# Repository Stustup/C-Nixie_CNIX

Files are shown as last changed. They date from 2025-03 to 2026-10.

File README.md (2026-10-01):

# CNIX - Nixie Tube Clock

CNIX is a nixie tube clock that can accept many diffrent nixie tubes with only slight modifications to the tube carrier board. 

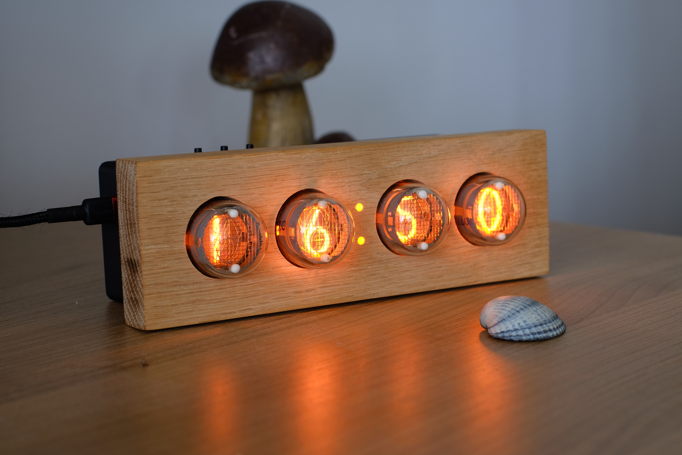
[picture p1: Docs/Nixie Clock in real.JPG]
Nixie Clock finished real picture


The motivation was that there are not many clocks out there that let you use almost any nixie tube you like. Most have fixed power supplies, 
underdesigned driver stages or inflexible microcontrollers. I hope to tackle these problems with an adjustable boost converter PSU, extremely 
flexible (and electrically protected) driver stages and an open source firmware written with free tools.

Nixie Clock PCB stackup

## **Schematic**

The control board consists of 3 parts:
- Power Supply
- Microcontroller
- I/O
- GPIO header

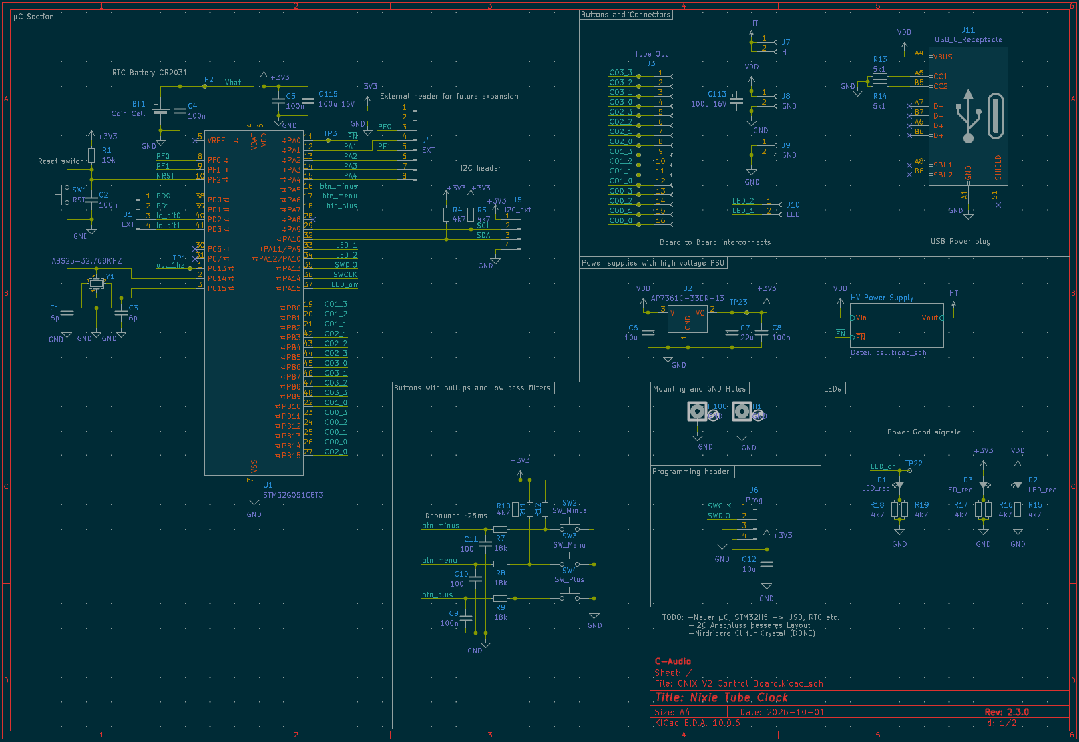
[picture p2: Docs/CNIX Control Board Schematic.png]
Control board schematic


Power comes from a simple USB-C plug configured for 5V 3A max with the 5k1 CC line resistors. I thought about adding a PD controller for higher input voltages, but this would just have added complexity and locked you into more expensive USB PD power supplies.

The µC is a STM32G051, because it has an included RTC *with* added Vbat pin for an external battery, so that the RTC remembers time even when powered off. 
The unused GPIOs are broken out to a connector, so that in the future one could add cool stuff like a radio time reciever, a display or wifi.
Time is set manually with the push buttons on top. 

The PSU is heavily inspired by [this site](https://surfncircuits.com/2018/02/03/optimizing-the-5v-to-170v-nixie-tube-power-supply-design-part-2/). I highly advise you giving it a read. The article goes in depth with boost converter design and its challanges.

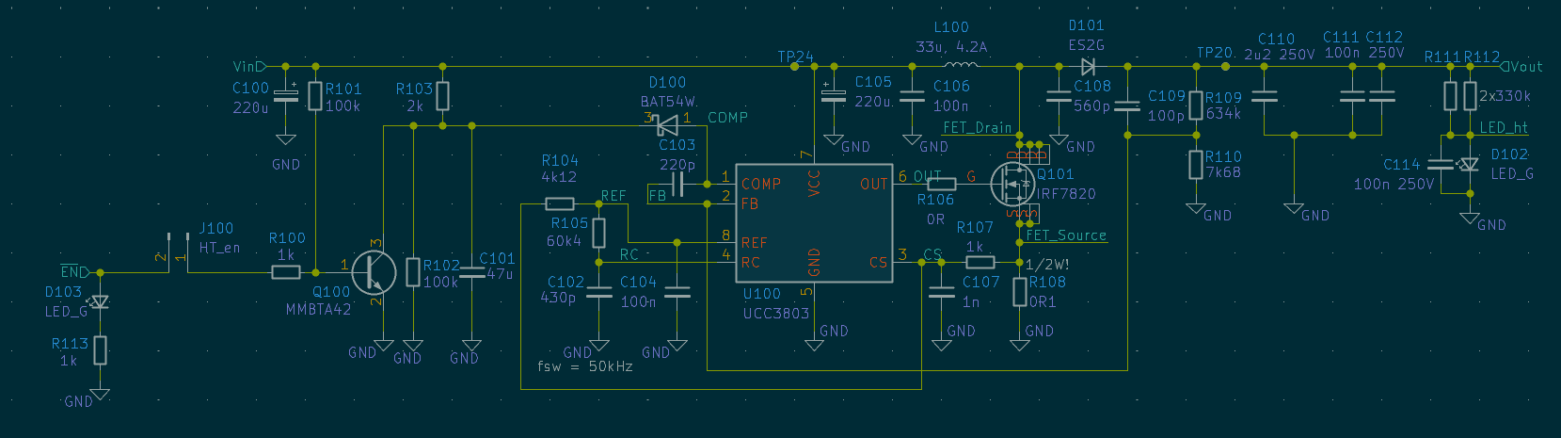
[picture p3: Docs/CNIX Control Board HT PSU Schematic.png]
HT Power supply

The ht power supply is a DCM boost converter powered by the UCC3803. An active low enable pin is realized via pulling the frequency RC combination low. With normal usage temperature of around 50-60°C are reached by the output transistor and the controller, which is a safe area. The case is designed so that a convection current of air is directed over the power supply at all times. This vent should not be blocked.  

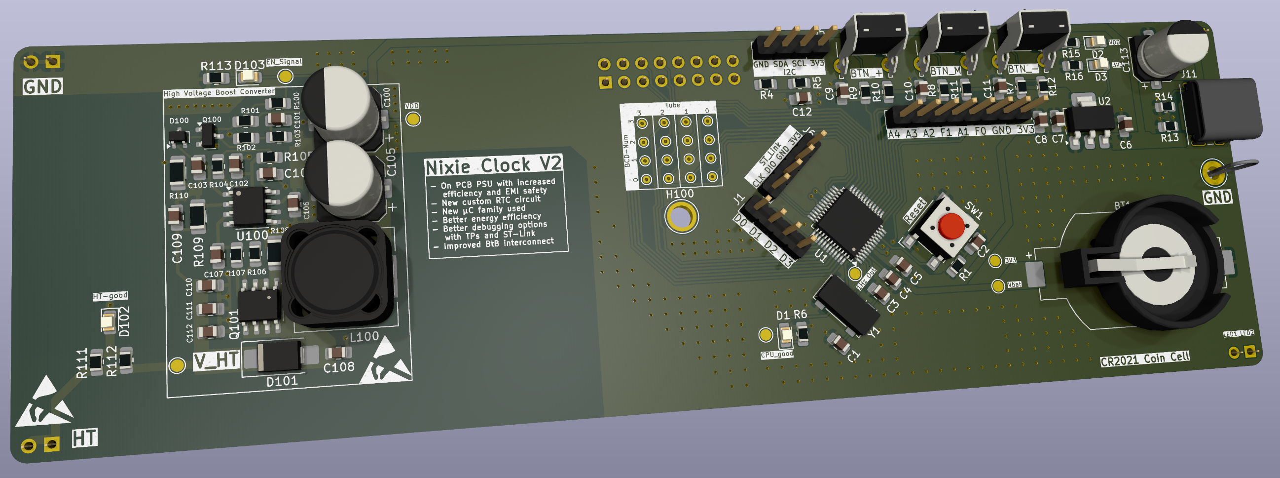
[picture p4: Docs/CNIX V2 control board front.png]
Control board 3d view


The driver consists of 4 CD4028 BCD to Decimal converters and 6 SN75468 high voltage drivers. The SN75468 only work up top 100V, but when using two 48V zener diodes as clamps, the voltage on the torned off digits never reach above 100V and above the startup voltage of the nixies. So win win.

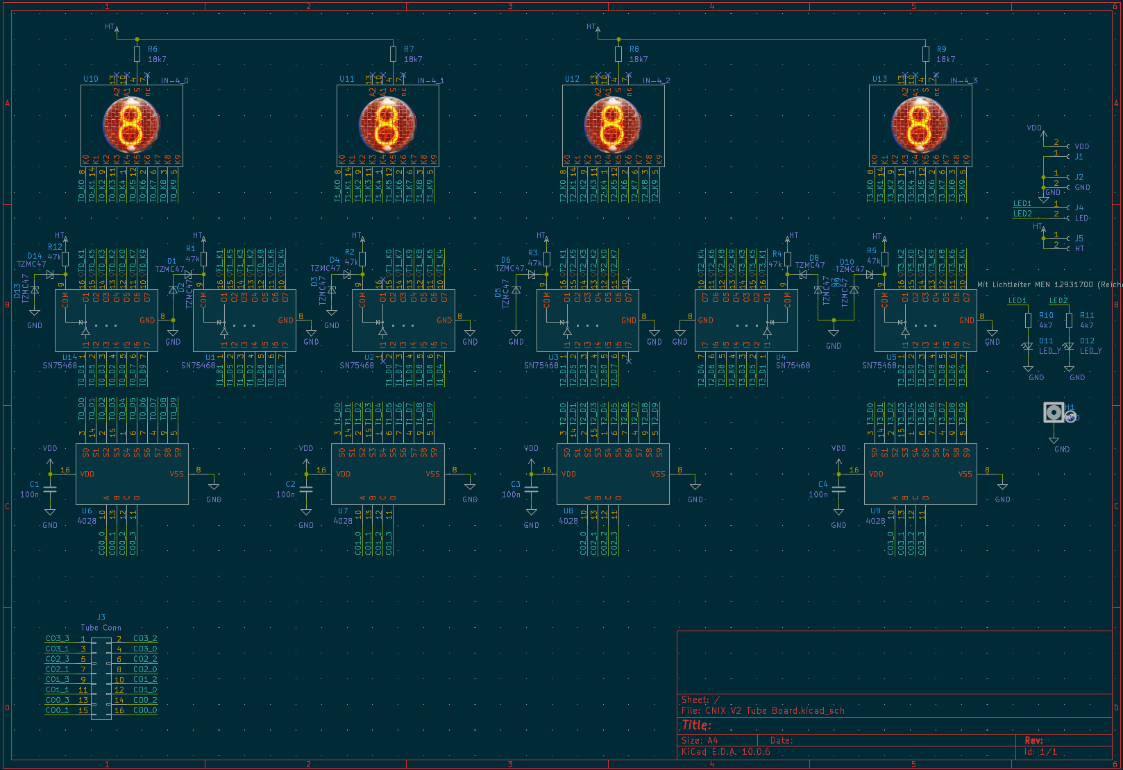
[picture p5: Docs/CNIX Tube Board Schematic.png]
Tube board schematic

I didn't use the old high voltage nixie driving shift registers as they are more and more hard to find for a reasonable price. Also i did not use shift registers at all, to simplify programming and wiring. Instead the whole Port B of the STM32 is used as a big 16 bit control register where the numbers are encoded in BCD. This ensures that there can not be 2 turned on digits at the same time in one tube to prevent bugs and damaging the beautiful nixies. 
Except the decoupling capacitors, diopdes and LEDS, everything is a simple to reflow solder IC, The tube pins have to be assembled manually (by putting them on a tube an inserting it into the holes before soldering it to ensure perfect alignment).  

The case is designed in FreeCAD and printed in PLA or PETG. Assembly is a bit of a hassle, but the fit is perfect. You can print a front plate, but i think the clock is vastly more beautiful when paired with a wooden front plate. Drill files for this are within the CAD folder. The holes for the LED front indicators can be filled with a 3mm lightpipe cut to length, to get a beautiful finish. 
Case, PCB and front plate are screwed together with 15mm M3 wood screws.

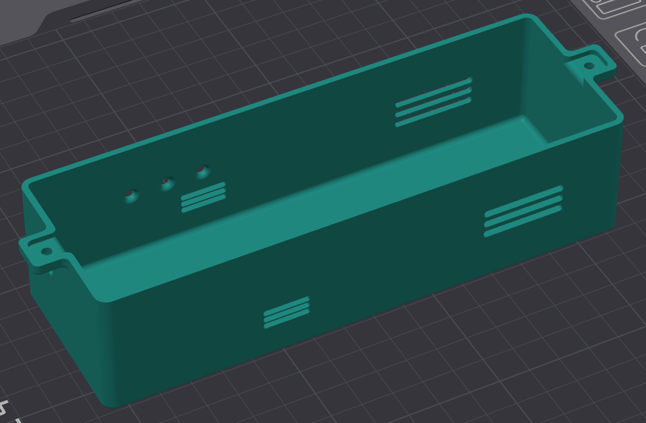
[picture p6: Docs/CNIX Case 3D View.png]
Case 3d view


## **Neat features**

### <u>Adaptability</u>
If you want to use any other nixie (up to around 5mA per tube of HT supply current) just modify the tube board PCB to fit your tubes. The driver, power supply and control logic should all be compatible with any other tube. Of course you have to modify the driving circuit when not using the simple common anode topology.

### <u>USB-C support</u>
Use any USB power supply with a minimum current of 1.7A (The startup of the boost converter needs a lot of current) Standard power consumption is around 2W (400mA at 5V) when the boost converter is powered on and around 0.2W (40mA at 5V) when the boost converter is powered down. 

### <u>Fallback structure</u>
If for some reason you change your mind while setting the start/stop times or the main time, just wait for around a minute. The menu will exit automatically, discard all changes and get back to the main time display.

### <u>Date and Sensor display</u>
Press the "plus" or "minus" buttons to cycle through submenus in this order: 
Main Time display -> Date display -> Sensor Display
These have a short timeout time to get back to the main Time menu. The sensor display gets disabled when there is no sensor addon board present.

### <u>Automatic daylight saving time (DST)</u>
The clock will calculate DST on its own and set the time correspondingly, even when the DCF77 module is not used.

### <u>Turn on/off timers</u>
You can set power on and off times in the clock natively, so that the nixies dont always glow. With this the HT-power supply also gets deactivated to save power and lifespan of the parts. 
There are two sets of start and stop times set by the buttons on the menu with the lower LED blinking.
The order is: Start1 -> Stop1 -> Start2 -> Stop2.
If all are set to 0, the start stop automatic gets disabled.
The start stop times are saved to a backup register of the µC, so the clock remembers them even when powered off as long as the RTC battery is present. 

#### Peek
When out of the "on" timeframes you can "peek" at the current time for 10s with a press of the menu-button. During these 10s you can jump to all the diffrent menus.

### <u>Addon Boards</u>
The breakout pins next to the µC can be used for addon boards. Pins D2 and D3 of the µC are used to detect those with an ID system. 
| ID | Board |
|---|---|
| 0b11  | No Addon board installed -> defualt |
| 0b00  | DCF77 Addon Board used |
| 0b01  | not yet used |
| 0b10  | not yet used |

Most of the hardware features of the STM32G051 should be mapped to the pins on the breakout. If not you're out of luck (it's open source, so just change it). Stuff like the ST-Link programming pins or I2C are broken out on extra headers to simplify future expansion.

#### DCF77 Addon Board
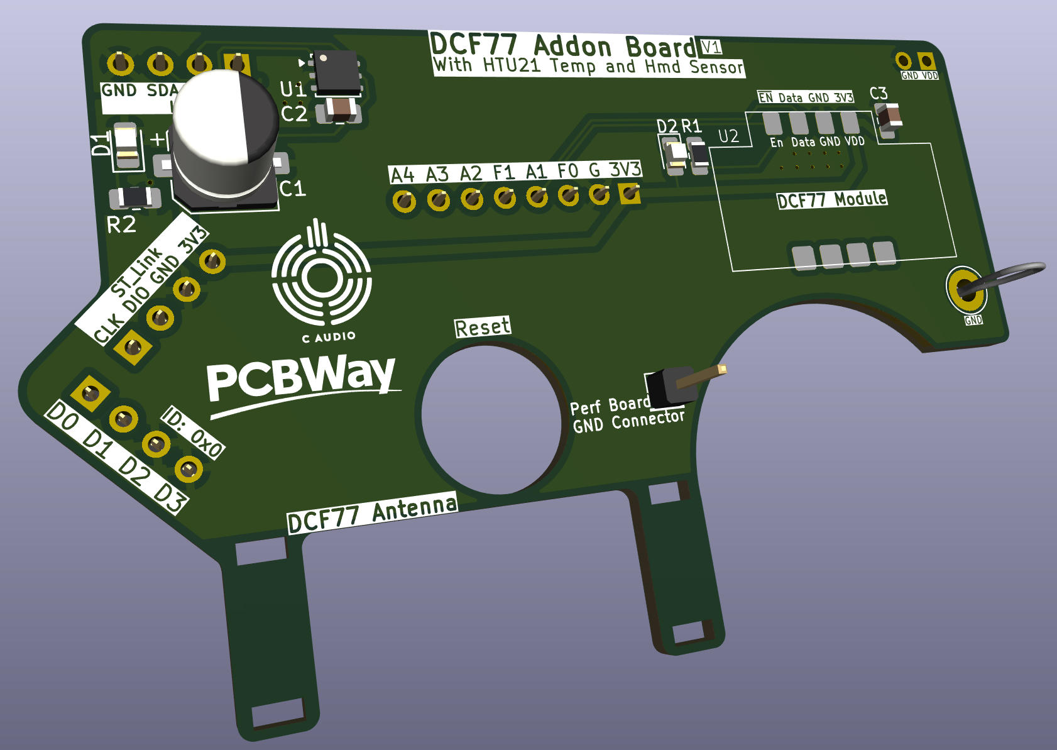
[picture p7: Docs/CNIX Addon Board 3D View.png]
DCF77 Addon Board

In germany (and most of europe) we have the DCF77 signal pushed out by the radio transmitter near Frankfurt. 
This board hosts a cheap module from ebay and a HTU21D temperature and humidity sensor. The driver is already programmed into the Control Board and gets enabled when this addon board is detected. 
When a valid time is recieved the manual timeSet menu gets disabled, to prevent fuckery.
It is setup, that every night at 2 an alarm gets triggered by the RTC to recalibrate time. If the  time-parity bit is not matched within a 20 minute timeout an attempt counter is incremented, which gets saved to a backup-register inside the RTC. As long as a RTC battery is powering the µC this register is kept even when the power is off. 
If the attempt counter reches 3 days without successful calibration against the radio time the manual timeSet menu gets enabled again.

On the DCF77 Addon board there is a single pin to give structural strength to a simple perfboard on the main breakout bus. One can use this in tandem with the A1, A2, A3, A4, F0 and F1 pins.

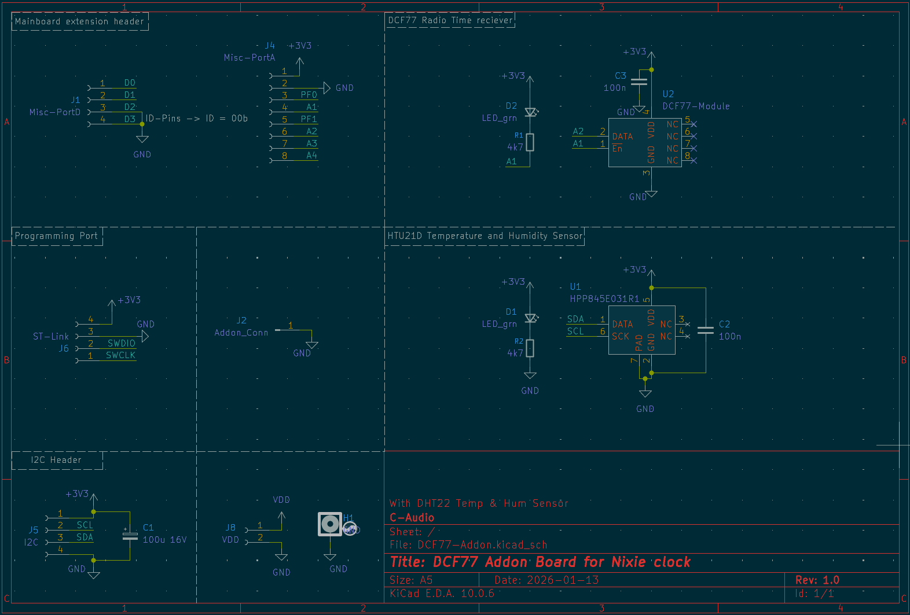
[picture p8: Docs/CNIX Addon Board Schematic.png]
DCF77 Addon Board


Ideas for future addon Boards: 
- ESP32 addon board to integrate WiFi time synchronisation or HomeAssistant integration
- Other sensors like air quality sensors
- maybe displays?

## TODO

- Change to new MCU. STM32H5 for USBC pd -> more efficient boost converter because higher input voltage
- Sleep modes during off times paired with wakeup alarms at start times -> reduce power consumption even more
- Improve the case to simplify assembly
- More tube boards to fit more types of nixies (IN-14 e.G.)
- BOM optimization to reduce number of unique parts
- galvanic isolation between high voltage areas and µC GPIOs

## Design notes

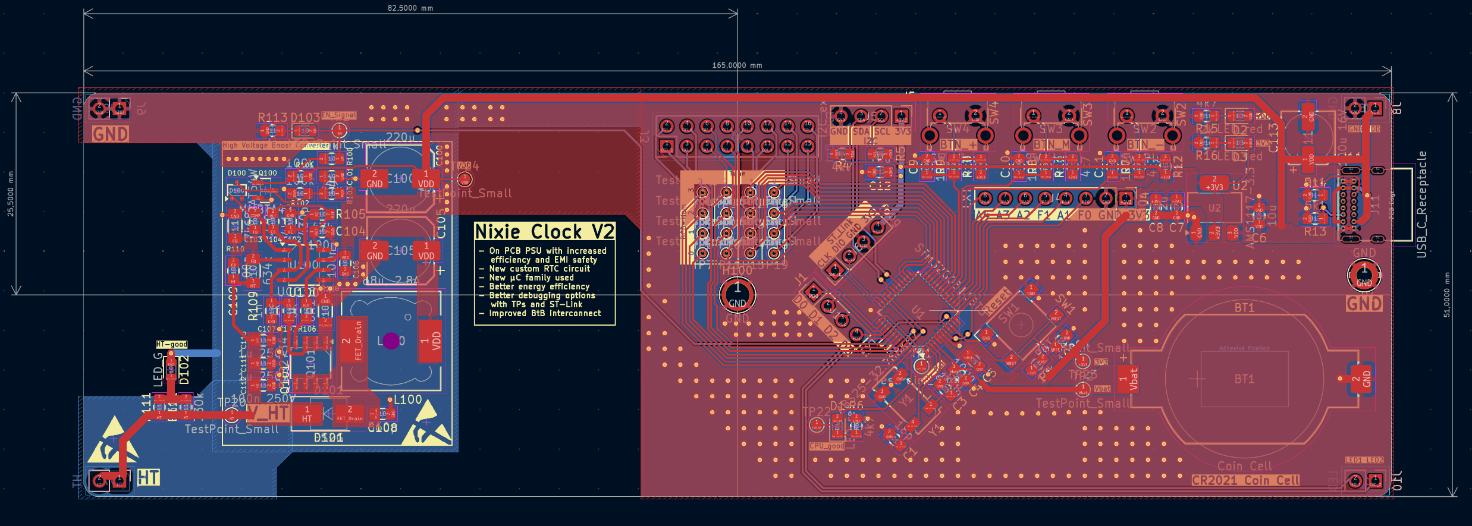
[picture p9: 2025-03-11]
Docs/CNIX V2 control board board.png

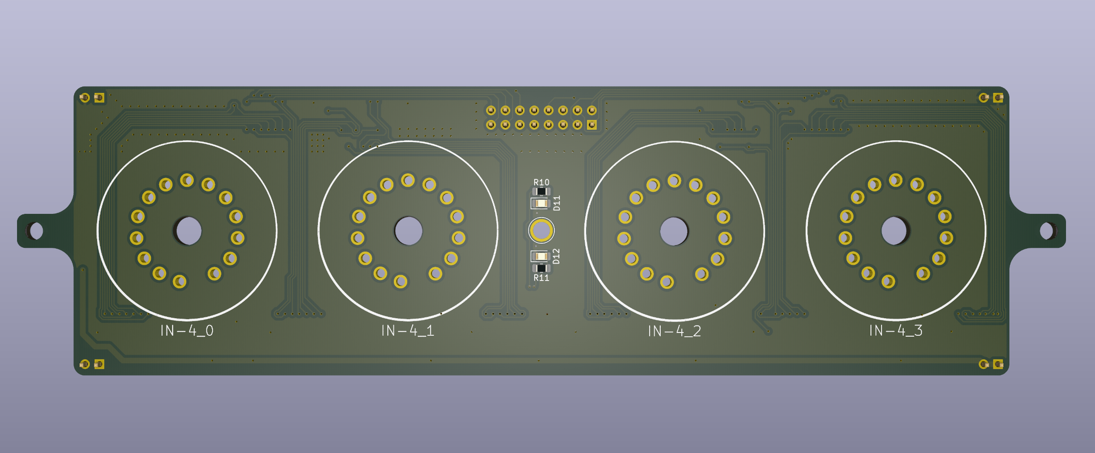
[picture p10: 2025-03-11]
Docs/CNIX V2 tube board front.png

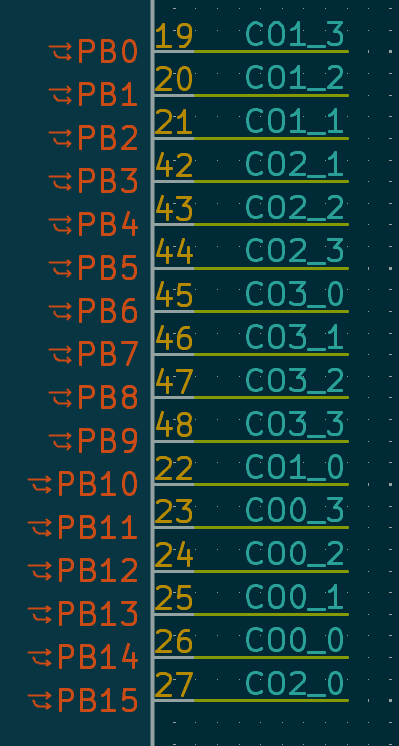
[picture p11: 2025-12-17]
Docs/Port mapping GPIOB.png

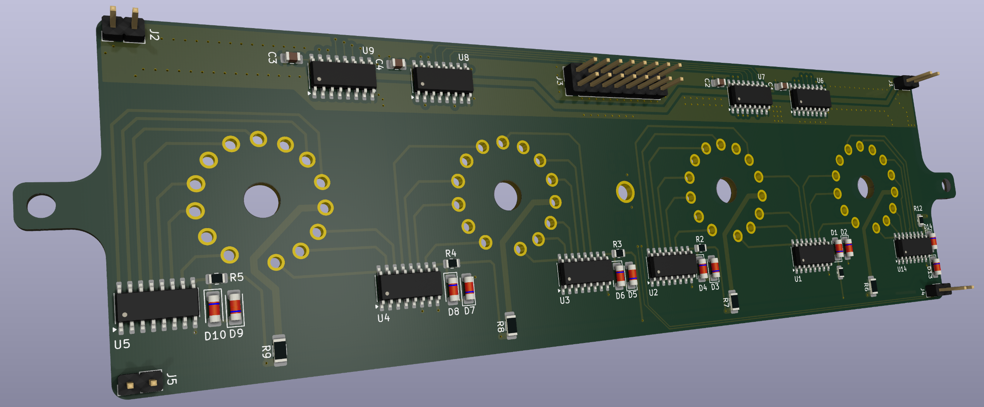
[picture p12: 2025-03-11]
Docs/CNIX V2 tube board side.png

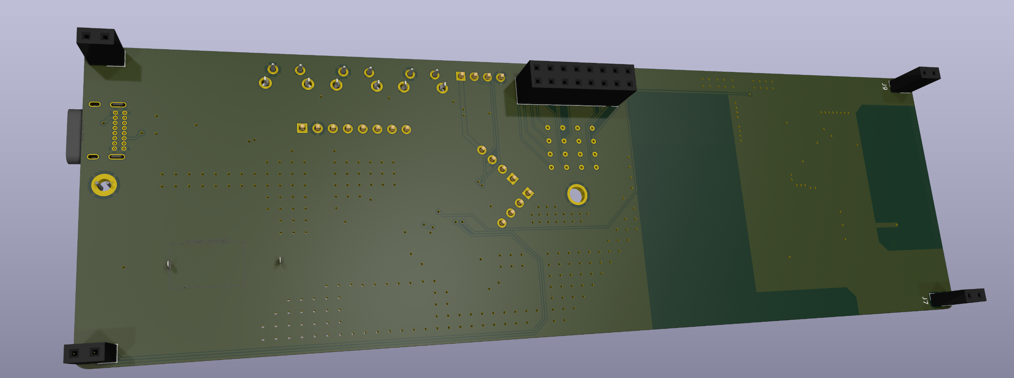
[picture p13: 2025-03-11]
Docs/CNIX V2 control board back.png

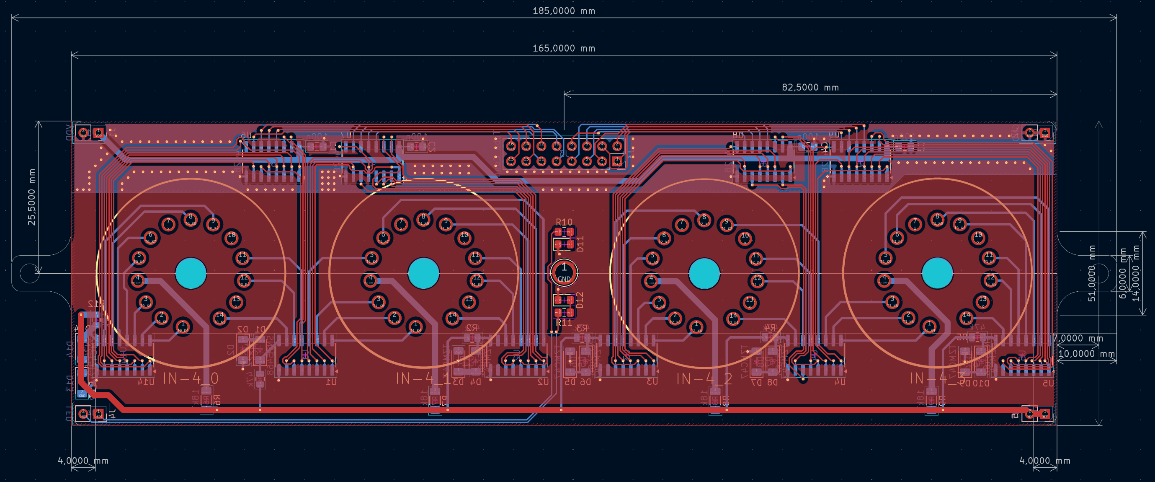
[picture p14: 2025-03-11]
Docs/CNIX V2 tube board board.png

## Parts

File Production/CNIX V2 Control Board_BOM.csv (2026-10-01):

Reference | Value | Qty | Mouser Nr. | Mouser URL | Datasheet | Footprint | DNP
BT1 | Coin Cell | 1 | 614-SMTU2032-LF.TR | https://www.mouser.de/ProductDetail/Renata/SMTU2032-LF.TR?qs=ZH26iPUykMX3HPCVulIAgQ%3D%3D | ~ | Battery:BatteryHolder_Renata_SMTU2032-LF_1x2032
C1,C3 | 18p | 2 | 80-C0805C180K5HACTU |  | ~ | Capacitor_SMD:C_0805_2012Metric_Pad1.18x1.45mm_HandSolder
C2,C4,C5,C8,C9,C10,C11,C104,C106 | 100n | 9 |  |  | ~ | Capacitor_SMD:C_0805_2012Metric_Pad1.18x1.45mm_HandSolder
C6,C12 | 10u | 2 | 187-CL21B106KPQNNNE |  | ~ | Capacitor_SMD:C_0805_2012Metric_Pad1.18x1.45mm_HandSolder
C7 | 22u | 1 | 187-CL21A226MQQNNNG |  | ~ | Capacitor_SMD:C_0805_2012Metric_Pad1.18x1.45mm_HandSolder
C100,C105 | 220u | 2 | 647-UUX1E221MNL6GS |  | ~ | Capacitor_SMD:CP_Elec_8x10
C101 | 47u | 1 | 187-CL21A476MRYNNNE |  | ~ | Capacitor_SMD:C_0805_2012Metric_Pad1.18x1.45mm_HandSolder
C102 | 430p | 1 | 80-C0805C431J5G |  | ~ | Capacitor_SMD:C_0805_2012Metric_Pad1.18x1.45mm_HandSolder
C103 | 220p | 1 | 710-885012207082 |  | ~ | Capacitor_SMD:C_0805_2012Metric_Pad1.18x1.45mm_HandSolder
C107 | 1n | 1 | 187-CL21B102KBANNNC |  | ~ | Capacitor_SMD:C_0805_2012Metric_Pad1.18x1.45mm_HandSolder
C108 | 560p | 1 | 80-C0805C561K2R |  | ~ | Capacitor_SMD:C_0805_2012Metric_Pad1.18x1.45mm_HandSolder
C109 | 100p | 1 | 581-08052C101K |  | ~ | Capacitor_SMD:C_0805_2012Metric_Pad1.18x1.45mm_HandSolder
C110,C111 | 1u 250V | 2 | 810-CGA4J3X7T2E104MA |  | ~ | Capacitor_SMD:C_0805_2012Metric_Pad1.18x1.45mm_HandSolder
C112 | 100n 250V | 1 | 810-CGA4J3X7T2E104MA |  | ~ | Capacitor_SMD:C_0805_2012Metric_Pad1.18x1.45mm_HandSolder
C113 | 100u 16V | 1 | 710-865080343009 | https://www.mouser.de/ProductDetail/Wurth-Elektronik/865080343009?qs=0KOYDY2FL28Gid9q%2FqirTQ%3D%3D | ~ | Capacitor_SMD:CP_Elec_6.3x7.7
D1,D2,D3 | LED_red | 3 |  |  | ~ | LED_SMD:LED_0805_2012Metric_Pad1.15x1.40mm_HandSolder
D100 | BAT54W | 1 | 637-BAT54W |  | https://assets.nexperia.com/documents/data-sheet/BAT54W_SER.pdf | Package_TO_SOT_SMD:SOT-323_SC-70
D101 | ES2G | 1 | 603-ES2G | https://eu.mouser.com/ProductDetail/YAGEO/ES2G?qs=2MMvu9PpTS2aUaVf2vcl5g%3D%3D | ~ | Diode_SMD:D_SMB_Handsoldering
D102,D103 | LED_G | 2 |  |  | ~ | LED_SMD:LED_0805_2012Metric
J1,J4 | EXT | 2 |  |  | ~ | Connector_PinHeader_2.54mm:PinHeader_1x04_P2.54mm_Vertical,Connector_PinHeader_2.54mm:PinHeader_1x08_P2.54mm_Vertical
J3 | Tube Out | 1 |  |  | ~ | Connector_PinSocket_2.54mm:PinSocket_2x08_P2.54mm_Vertical
J5 | I2C_ext | 1 |  |  | ~ | Connector_PinHeader_2.54mm:PinHeader_1x04_P2.54mm_Vertical
J6 | Prog | 1 |  |  | ~ | Connector_PinHeader_2.54mm:PinHeader_1x04_P2.54mm_Vertical
J7 | HT | 1 |  |  | ~ | Connector_PinSocket_2.54mm:PinSocket_1x02_P2.54mm_Vertical
J8,J9 | GND | 2 |  |  | ~ | Connector_PinSocket_2.54mm:PinSocket_1x02_P2.54mm_Vertical
J10 | LED | 1 |  |  | ~ | Connector_PinSocket_2.54mm:PinSocket_1x02_P2.54mm_Vertical
J11 | USB_C_Receptacle | 1 |  |  | https://www.usb.org/sites/default/files/documents/usb_type-c.zip | Connector_USB:USB_C_Receptacle_GCT_USB4085
L100 | 68u, 2.8A | 1 | 871-B82477R4683M100 | https://www.mouser.de/ProductDetail/EPCOS-TDK/B82477R4683M100?qs=oQHyZtUHWNVcdFSxmnJQSQ%3D%3D | ~ | Inductor_SMD:L_12x12mm_H8mm
Q100 | MMBTA42 | 1 |  |  | https://www.onsemi.com/pub/Collateral/MMBTA42LT1-D.PDF | Package_TO_SOT_SMD:SOT-23
Q101 | FDS2734 | 1 | 512-FDS2734 | https://eu.mouser.com/ProductDetail/onsemi-Fairchild/FDS2734?qs=OZ%252BC78tOsDbAOUY0TECDsw%3D%3D | https://ngspice.sourceforge.io/docs/ngspice-html-manual/manual.xhtml#cha_MOSFETs | Package_SO:SO-8_3.9x4.9mm_P1.27mm
R1 | 10k | 1 |  |  | ~ | Resistor_SMD:R_0805_2012Metric_Pad1.20x1.40mm_HandSolder
R4,R5,R6,R7,R8,R9,R10,R11,R12,R15 | 4k7 | 10 | 603-RC0805FR-074K7P |  | ~ | Resistor_SMD:R_0805_2012Metric_Pad1.20x1.40mm_HandSolder
R13,R14 | 5k1 | 2 | 652-CR0805FX-5101ELF |  | ~ | Resistor_SMD:R_0805_2012Metric_Pad1.20x1.40mm_HandSolder
R16,R103 | 2k | 2 | 603-RC0805FR-132KL |  | ~ | Resistor_SMD:R_0805_2012Metric_Pad1.20x1.40mm_HandSolder
R100,R107,R113 | 1k | 3 |  |  | ~ | Resistor_SMD:R_0805_2012Metric_Pad1.20x1.40mm_HandSolder
R101,R102 | 100k | 2 |  |  | ~ | Resistor_SMD:R_0805_2012Metric_Pad1.20x1.40mm_HandSolder
R104 | 4k12 | 1 | 603-RC0805FR-074K12L |  | ~ | Resistor_SMD:R_0805_2012Metric_Pad1.20x1.40mm_HandSolder
R105 | 47k | 1 | 603-RE0805FRE0747KL |  | ~ | Resistor_SMD:R_0805_2012Metric_Pad1.20x1.40mm_HandSolder
R106 | 0R | 1 |  |  | ~ | Resistor_SMD:R_0805_2012Metric_Pad1.20x1.40mm_HandSolder
R108 | 0R1 | 1 | 660-UR73VH2BTTDR100F | https://www.mouser.de/ProductDetail/KOA-Speer/UR73VH2BTTDR100F?qs=HoCaDK9Nz5dTWFlShnTmnw%3D%3D | https://www.koaspeer.com/pdfs/UR73V.pdf | Resistor_SMD:R_1206_3216Metric_Pad1.30x1.75mm_HandSolder
R109 | 634k | 1 | 71-CRCW0805634KFKEA |  | ~ | Resistor_SMD:R_1206_3216Metric_Pad1.30x1.75mm_HandSolder
R110 | 7k68 | 1 | 603-RC0805FR-077K68L |  | ~ | Resistor_SMD:R_1206_3216Metric_Pad1.30x1.75mm_HandSolder
R111,R112 | 330k | 2 | 603-AC0805FR-07330KL |  | ~ | Resistor_SMD:R_0805_2012Metric_Pad1.20x1.40mm_HandSolder
SW1 | RST | 1 |  |  | ~ | Button_Switch_SMD:SW_SPST_Omron_B3FS-100xP
SW2 | SW_Plus | 1 |  |  | ~ | Button_Switch_THT:SW_Tactile_SPST_Angled_PTS645Vx31-2LFS
SW3 | SW_Menu | 1 |  |  | ~ | Button_Switch_THT:SW_Tactile_SPST_Angled_PTS645Vx31-2LFS
SW4 | SW_Minus | 1 |  |  | ~ | Button_Switch_THT:SW_Tactile_SPST_Angled_PTS645Vx31-2LFS
TP1,TP2,TP3,TP4,TP5,TP6,TP7,TP8,TP9,TP10,TP11,TP12,TP13,TP14,TP15,TP16,TP17,TP18,TP19,TP20,TP22,TP23,TP24 | TestPoint_Small | 23 |  |  | ~ | TestPoint:TestPoint_Pad_D1.5mm,TestPoint:TestPoint_THTPad_D1.0mm_Drill0.5mm
U1 | STM32G051C8T3 | 1 | 511-STM32G051C8T3 | https://www.mouser.de/ProductDetail/STMicroelectronics/STM32G051C8T3?qs=T%252BzbugeAwjiuqacRoZ%252BJAg%3D%3D | https://www.mouser.de/datasheet/2/389/stm32g051c6-2449954.pdf | Package_QFP:LQFP-48_7x7mm_P0.5mm
U2 | AMS1117-3.3 | 1 |  |  | http://www.advanced-monolithic.com/pdf/ds1117.pdf | Package_TO_SOT_SMD:SOT-223-3_TabPin2
U100 | UCC3803 | 1 | 595-UCC3803DTR |  | http://www.ti.com/lit/ds/symlink/ucc3800.pdf | Package_SO:SOIC-8_3.9x4.9mm_P1.27mm
Y1 | ABS25-32.768KHZ | 1 | 815-ABS25-32.7-6-1-T | https://www.mouser.de/ProductDetail/ABRACON/ABS25-32.768KHZ-6-1-T?qs=3LVMET7lfiORXXovA%252BX5Lg%3D%3D | ~ | Crystal:Crystal_SMD_Abracon_ABS25-4Pin_8.0x3.8mm

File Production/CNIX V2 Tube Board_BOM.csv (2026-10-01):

Reference | Value | Qty | Mouser URL | Mouser Nr. | Datasheet | Footprint | DNP
C1,C2,C3,C4 | 100n | 4 |  |  | ~ | Capacitor_SMD:C_0805_2012Metric_Pad1.18x1.45mm_HandSolder
D1,D2,D3,D4,D5,D6,D7,D8,D9,D10,D13,D14 | TZMC47 | 12 | 78-TZMC47 |  | ~ | Diode_SMD:D_MiniMELF
D11,D12 | LED_Y | 2 |  |  | ~ | LED_SMD:LED_0805_2012Metric_Pad1.15x1.40mm_HandSolder
J1 | VDD | 1 |  |  | ~ | Connector_PinHeader_2.54mm:PinHeader_1x02_P2.54mm_Vertical
J2 | GND | 1 |  |  | ~ | Connector_PinHeader_2.54mm:PinHeader_1x02_P2.54mm_Vertical
J3 | Tube Conn | 1 |  |  | ~ | Connector_PinHeader_2.54mm:PinHeader_2x08_P2.54mm_Vertical
J4 | LED | 1 |  |  | ~ | Connector_PinHeader_2.54mm:PinHeader_1x02_P2.54mm_Vertical
J5 | HT | 1 |  |  | ~ | Connector_PinHeader_2.54mm:PinHeader_1x02_P2.54mm_Vertical
R1,R2,R3,R4,R5,R12 | 47k | 6 |  | 603-AC0805FR-1347KL | ~ | Resistor_SMD:R_0805_2012Metric
R6,R7,R8,R9 | 18k7 | 4 |  | 603-RC1206FR-0718K7L | ~ | Resistor_SMD:R_1206_3216Metric_Pad1.30x1.75mm_HandSolder
R10,R11 | 4k7 | 2 |  | 603-RC0805FR-074K7P | ~ | Resistor_SMD:R_0805_2012Metric_Pad1.20x1.40mm_HandSolder
U1,U2,U3,U4,U5,U14 | SN75468 | 6 | https://www.mouser.de/ProductDetail/Texas-Instruments/SN75468DR?qs=o4busQjUnQYJjs5DwORJyA%3D%3D | 595-SN75468DR | http://www.ti.com/lit/ds/slrs023e/slrs023e.pdf | Package_SO:SOIC-16_3.9x9.9mm_P1.27mm
U6,U7,U8,U9 | 4028 | 4 |  | 595-CD4028BM96 | http://www.intersil.com/content/dam/Intersil/documents/cd40/cd4028bms.pdf | Package_SO:SOIC-16_3.9x9.9mm_P1.27mm
U10 | IN-4_0 | 1 |  |  | https://www.tube-tester.com/sites/nixie/data/in-4/in-4-sh2.htm | .Nixie Tubes:IN-4
U11 | IN-4_1 | 1 |  |  | https://www.tube-tester.com/sites/nixie/data/in-4/in-4-sh2.htm | .Nixie Tubes:IN-4
U12 | IN-4_2 | 1 |  |  | https://www.tube-tester.com/sites/nixie/data/in-4/in-4-sh2.htm | .Nixie Tubes:IN-4
U13 | IN-4_3 | 1 |  |  | https://www.tube-tester.com/sites/nixie/data/in-4/in-4-sh2.htm | .Nixie Tubes:IN-4

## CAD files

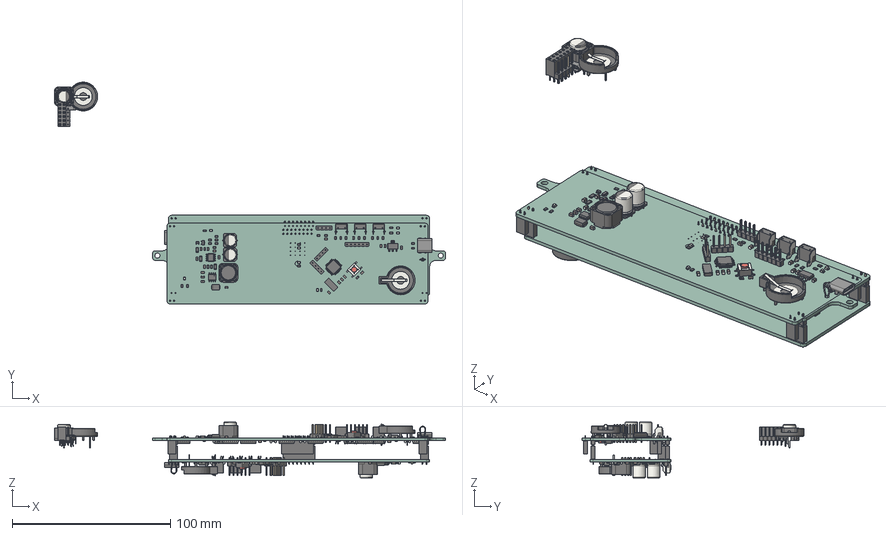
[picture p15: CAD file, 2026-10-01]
CAD/3D Models/Nixie Clock 2 combined.step
247.0 x 140.1 x 35.3 mm
R_1206_3216Metric x 3
X-Achse x 396
XY-Ebene x 396
C_0805_2012Metric x 3
C_0805_2012Metric002 x 3
C_0805_2012Metric004 x 3
C_0805_2012Metric006 x 3
R_0805_2012Metric x 3
LED_0805_2012Metric x 3
C_0805_2012Metric008 x 3
C_0805_2012Metric010 x 3
C_0805_2012Metric012 x 3
R_0805_2012Metric002 x 3
C_0805_2012Metric014 x 3
R_0805_2012Metric004 x 3
R_0805_2012Metric006 x 3
C_0805_2012Metric016 x 3
C_0805_2012Metric018 x 3
R_0805_2012Metric008 x 3
C_0805_2012Metric020 x 3
R_0805_2012Metric010 x 3
R_0805_2012Metric012 x 3
R_0805_2012Metric014 x 3
MicroCrystal_CC1V_T1A x 3
R_0805_2012Metric016 x 3
R_1206_3216Metric002 x 3
C_0805_2012Metric022 x 3
R_0805_2012Metric018 x 3
R_0805_2012Metric020 x 3
C_0805_2012Metric024 x 3
R_0805_2012Metric022 x 3
TestPoint_Loop_D3.80mm_Drill2.0mm x 3
SW_Tactile_SPST_Angled_PTS645Vx31-2LFS x 3
SOT_23 x 3
PinHeader_1x06_P254mm_Vertical x 3
C_0805_2012Metric026 x 3
R_0805_2012Metric024 x 3
C_0805_2012Metric028 x 3
C_0805_2012Metric030 x 3
R_0805_2012Metric026 x 3
C_0805_2012Metric032 x 3
SW_Tactile_SPST_Angled_PTS645Vx31-2LFS002 x 3
L_Coilcraft_MSS1278-XXX x 3
R_0805_2012Metric028 x 3
SOT_323_SC_70 x 3
R_0805_2012Metric030 x 3
C_0805_2012Metric034 x 3
R_0805_2012Metric032 x 3
LED_0805_2012Metric002 x 3
CP_Elec_8x10 x 3
C_0805_2012Metric036 x 3
R_0805_2012Metric034 x 3
R_0805_2012Metric036 x 3
SOIC_8_39x49mm_P127mm x 3
CQ assembly x 4
CQ assembly001 x 4
CQ assembly002 x 4
CQ assembly003 x 4
CQ assembly004 x 4
CQ assembly005 x 4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

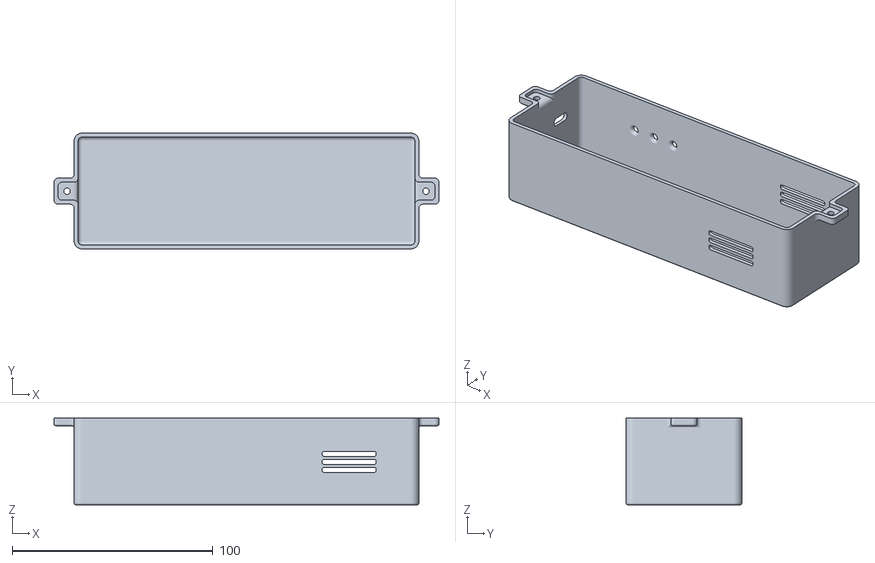
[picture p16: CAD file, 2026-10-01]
CAD/Case/Nixie Clock 2 Case 3d-printing_2.stl
192.0 x 57.8 x 43.2

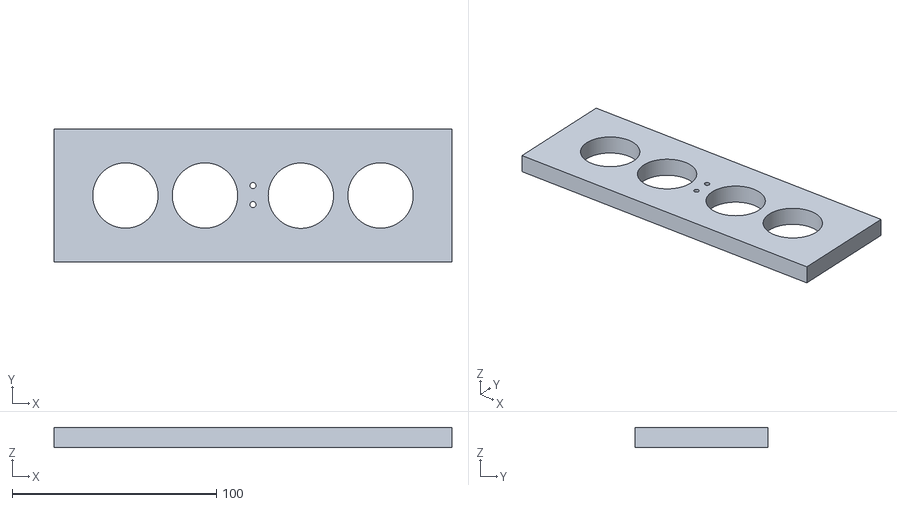
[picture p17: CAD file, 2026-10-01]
CAD/Front Plate/Nixie Clock 2 Frontplate routing template.stl
195.0 x 65.0 x 10.0

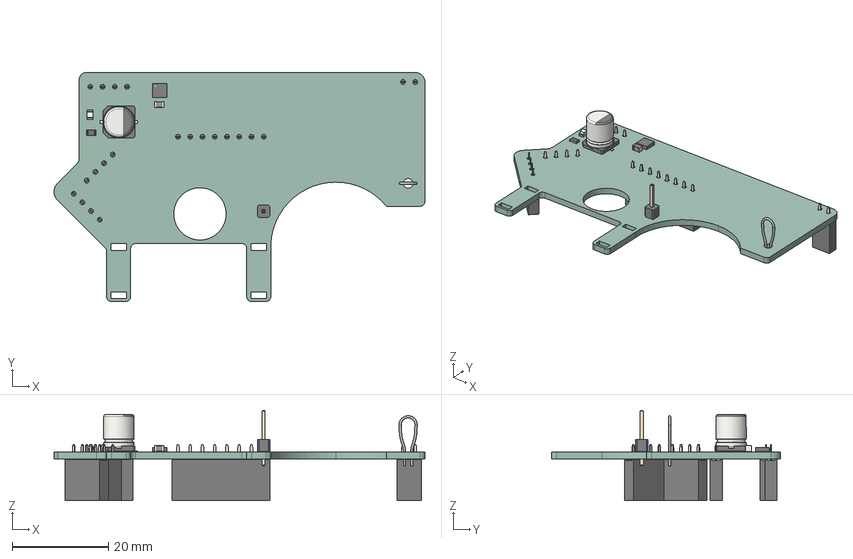
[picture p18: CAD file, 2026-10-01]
Hardware/Addon Boards/DCF77-Addon/3D/DCF77-Addon.step
77.0 x 47.5 x 18.7 mm
TestPoint_Loop_D3.80mm_Drill2.0mm
R_0805_2012Metric
CP_Elec_6.3x7.7
PinHeader_1x01_P2.54mm_Vertical
C_0805_2012Metric
LED_0805_2012Metric
DFN-6-1EP_3x3mm_P0.95mm_EP1.7x2.6mm
PinSocket_1x02_P2.54mm_Vertical
PinSocket_1x04_P2.54mm_Vertical x 3
PinSocket_1x08_P2.54mm_Vertical
DCF77-Addon_PCB

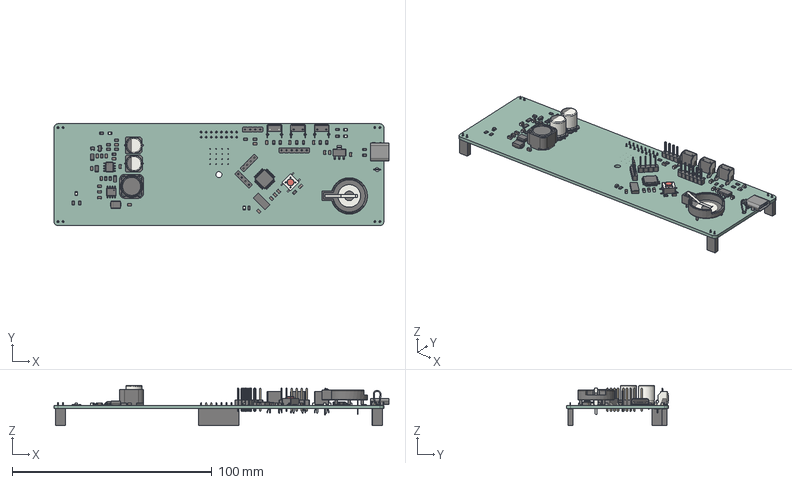
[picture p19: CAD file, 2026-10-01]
Hardware/Control Board/CNIX V2 Control Board/CNIX V2 Control Board.step
167.6 x 51.2 x 20.2 mm
R_1206_3216Metric x 3
C_0805_2012Metric x 23
R_0805_2012Metric x 25
LED_0805_2012Metric x 5
MicroCrystal_CC1V_T1A
TestPoint_Loop_D3.80mm_Drill2.0mm
SW_Tactile_SPST_Angled_PTS645Vx31-2LFS x 3
SOT_23
PinHeader_1x06_P254mm_Vertical
L_Coilcraft_MSS1278-XXX
SOT_323_SC_70
CP_Elec_8x10 x 2
SOIC_8_39x49mm_P127mm
CQ assembly
D_SMB
LQFP_48_7x7mm_P05mm
PinHeader_1x04_P254mm_Vertical x 3
Keystone_103
USB_C_Receptacle_GCT_USB4085
SOT_223
SW_SPST_PTS645
PinSocket_2x08_P2.54mm_Vertical
PinSocket_1x02_P2.54mm_Vertical x 4
_autosave-NixieClock control board_PCB

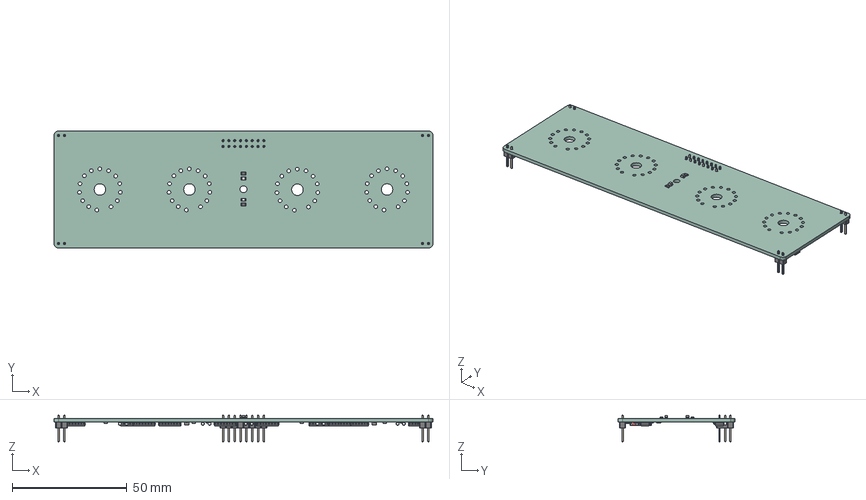
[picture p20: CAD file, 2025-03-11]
Hardware/Tube Board/CNIX V2 Tube Board IN13 (Placeholder)/CNIX V2 Tube Board.step
165.0 x 51.0 x 11.5 mm
R_0805_2012Metric x 8
LED_0805_2012Metric x 2
D_MiniMELF_Standard x 12
PinHeader_1x02_P254mm_Vertical x 4
SOIC_16_39x99mm_P127mm x 10
C_0805_2012Metric x 4
R_1206_3216Metric x 4
PinHeader_2x08_P254mm_Vertical
_autosave-Nixie Clock Tube Board V2_PCB

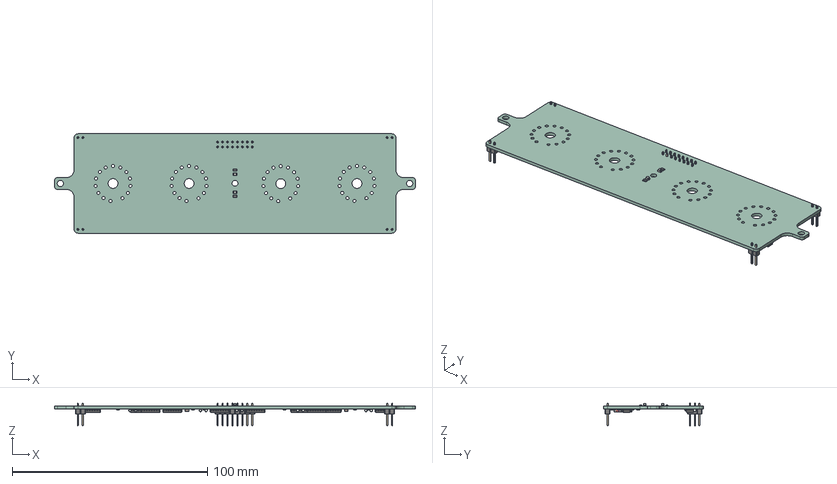
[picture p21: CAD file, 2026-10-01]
CAD/3D Models/Nixie Clock Tube Board V2 IN4.step
185.0 x 51.0 x 11.5 mm
R_0805_2012Metric x 8
LED_0805_2012Metric x 2
D_MiniMELF x 12
PinHeader_1x02_P2.54mm_Vertical x 4
SOIC-16_3.9x9.9mm_P1.27mm x 10
C_0805_2012Metric x 4
R_1206_3216Metric x 4
PinHeader_2x08_P2.54mm_Vertical
CNIX V2 Tube Board_PCB

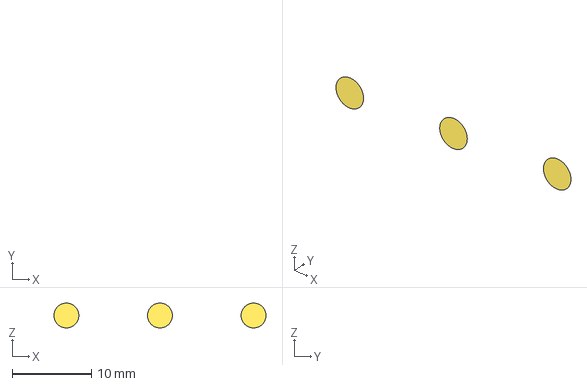
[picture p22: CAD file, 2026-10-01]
CAD/3D Models/Nixie Clock 2 Case 3d-printing.step
26.7 x 0 x 3.14 mm

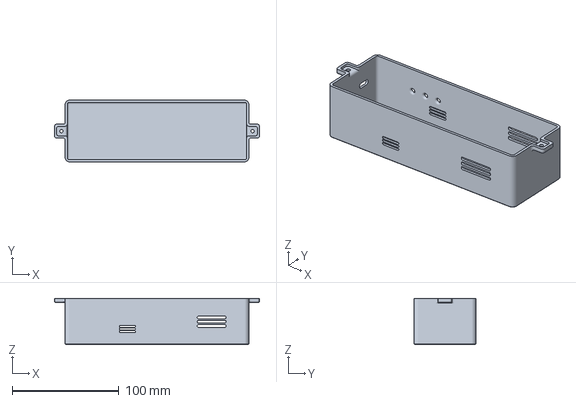
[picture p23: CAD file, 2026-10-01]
CAD/Case/Nixie Clock 2 Case 3d-printing_3.3mf
192.0 x 57.8 x 43.2 mm

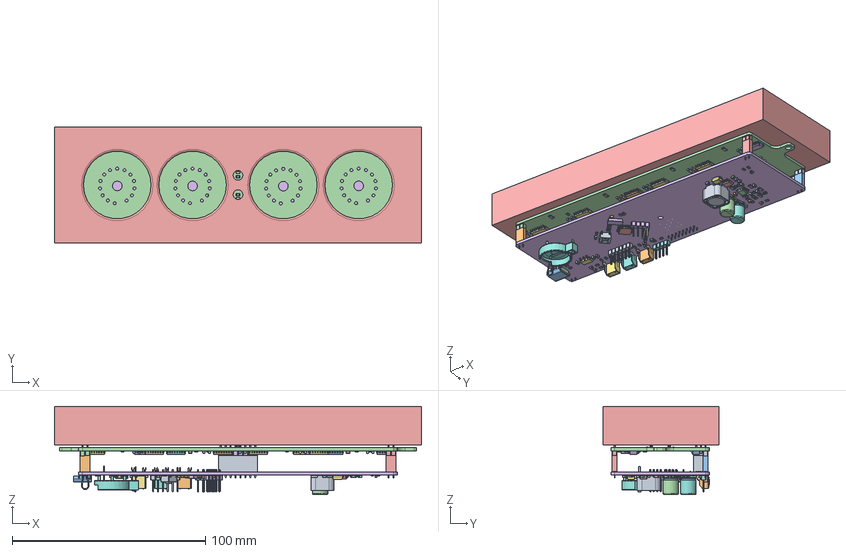
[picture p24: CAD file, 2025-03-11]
CAD/3D Models/Nixie Clock .FCStd
190.0 x 60.0 x 45.7 mm
R_1206_3216Metric
C_0805_2012Metric
C_0805_2012Metric002
C_0805_2012Metric004
C_0805_2012Metric006
R_0805_2012Metric
LED_0805_2012Metric
C_0805_2012Metric008
C_0805_2012Metric010
C_0805_2012Metric012
R_0805_2012Metric002
C_0805_2012Metric014
R_0805_2012Metric004
R_0805_2012Metric006
C_0805_2012Metric016
C_0805_2012Metric018
R_0805_2012Metric008
C_0805_2012Metric020
R_0805_2012Metric010
R_0805_2012Metric012
R_0805_2012Metric014
MicroCrystal_CC1V_T1A
R_0805_2012Metric016
R_1206_3216Metric002
C_0805_2012Metric022
R_0805_2012Metric018
R_0805_2012Metric020
C_0805_2012Metric024
R_0805_2012Metric022
TestPoint_Loop_D3.80mm_Drill2.0mm
SW_Tactile_SPST_Angled_PTS645Vx31-2LFS
SOT_23
PinHeader_1x06_P254mm_Vertical
C_0805_2012Metric026
R_0805_2012Metric024
C_0805_2012Metric028
C_0805_2012Metric030
R_0805_2012Metric026
C_0805_2012Metric032
SW_Tactile_SPST_Angled_PTS645Vx31-2LFS002
L_Coilcraft_MSS1278-XXX
R_0805_2012Metric028
SOT_323_SC_70
R_0805_2012Metric030
C_0805_2012Metric034
R_0805_2012Metric032
LED_0805_2012Metric002
CP_Elec_8x10
C_0805_2012Metric036
R_0805_2012Metric034
R_0805_2012Metric036
SOIC_8_39x49mm_P127mm
CQ assembly
CQ assembly001
CQ assembly002
CQ assembly003
CQ assembly004
CQ assembly005
CQ assembly006
CQ assembly007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

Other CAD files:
CAD/3D Models/Case.FCStd
CAD/3D Models/CNIX V2 Control Board.step
CAD/3D Models/CNIX V2 Tube Board.step
CAD/3D Models/Nixie Clock 2.FCStd
CAD/3D Models/Nixie Clock 2 combined.FCStd
CAD/Case/Nixie Clock 2 Case 3d-printing_3.stl
Hardware/Addon Boards/DCF77-Addon/3D/DCF77 Addon.FCStd

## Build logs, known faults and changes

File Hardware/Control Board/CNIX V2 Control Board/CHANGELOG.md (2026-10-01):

# Changelog for the Nixie Tube Clock Control Board

## Version 2.0.0
- New MCU (STM32G051C8T3)
- New fully integrated high voltage power supply
- Fully integrated RTC
- USB-C power supply

### V2.1.0
- Switchted from AMS1117 to AP7361C voltage regulator (drop in replacement) for better stability

### V2.1.1
- Fixed CR2025 label

### V2.2.0
- Added detection for addon modules via pins D2 and D3 (2 bit). DCF77 board has the id 0x0
- Added pin header with jumper for the HT-PSU for safe debugging and prototyping

## V2.3.0
- Cleanup of all directories
- Touchups on PCBs (LED placement ect.)
- HT PSU optimization
- Debounce filter optimization

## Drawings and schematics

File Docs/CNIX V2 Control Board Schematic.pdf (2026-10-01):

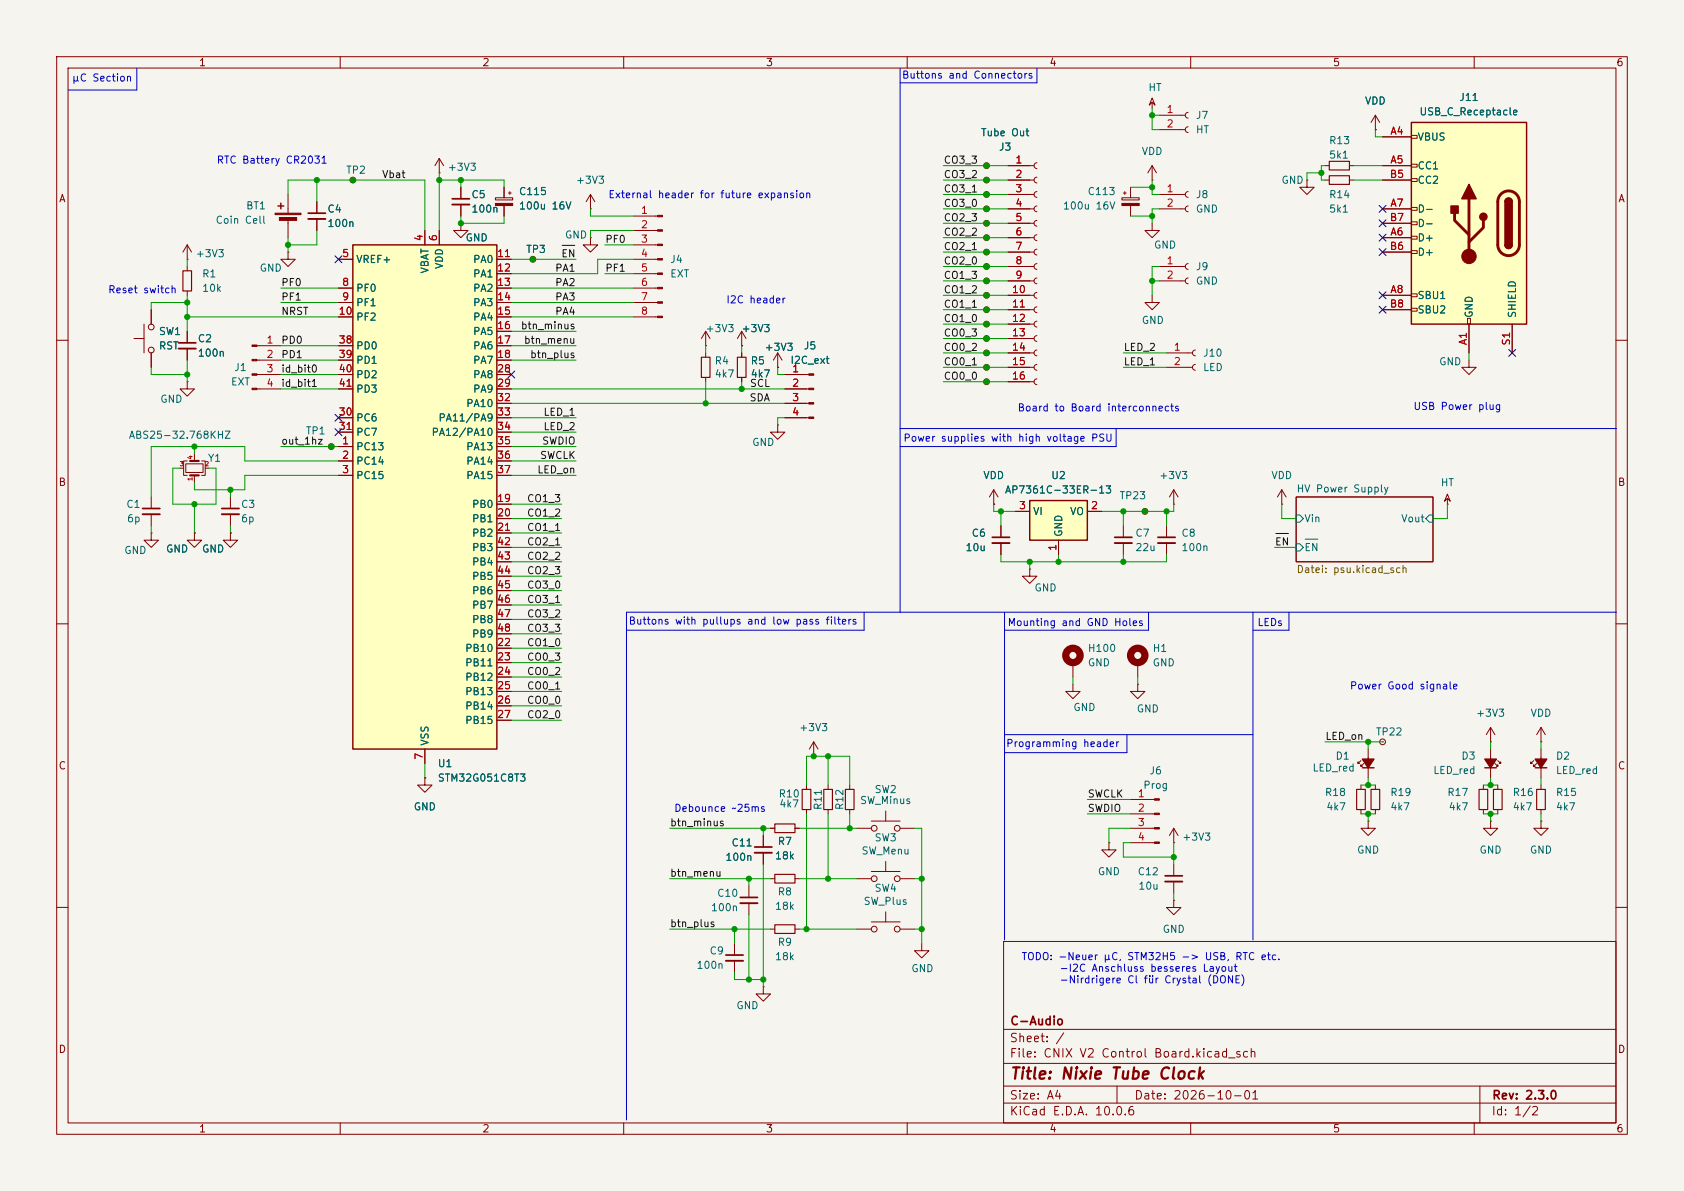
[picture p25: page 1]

LED_1 Buttons and Connectors Debounce ~25ms
GND HT +3V3

Board to Board interconnects Reset switch µC Section
100n GND

HV Power Supply Datei: psu.kicad_sch R4

TODO: -Neuer µC, STM32H5 -> USB, RTC etc. -I2C Anschluss besseres Layout

-Nirdrigere Cl für Crystal (DONE)

C-Audio
Sheet: /
File: CNIX V2 Control Board.kicad_sch
Title: Nixie Tube Clock

Size: A4 | Rev: 2.3.0
KiCad E.D.A. 10.0.6 | Id: 1/2

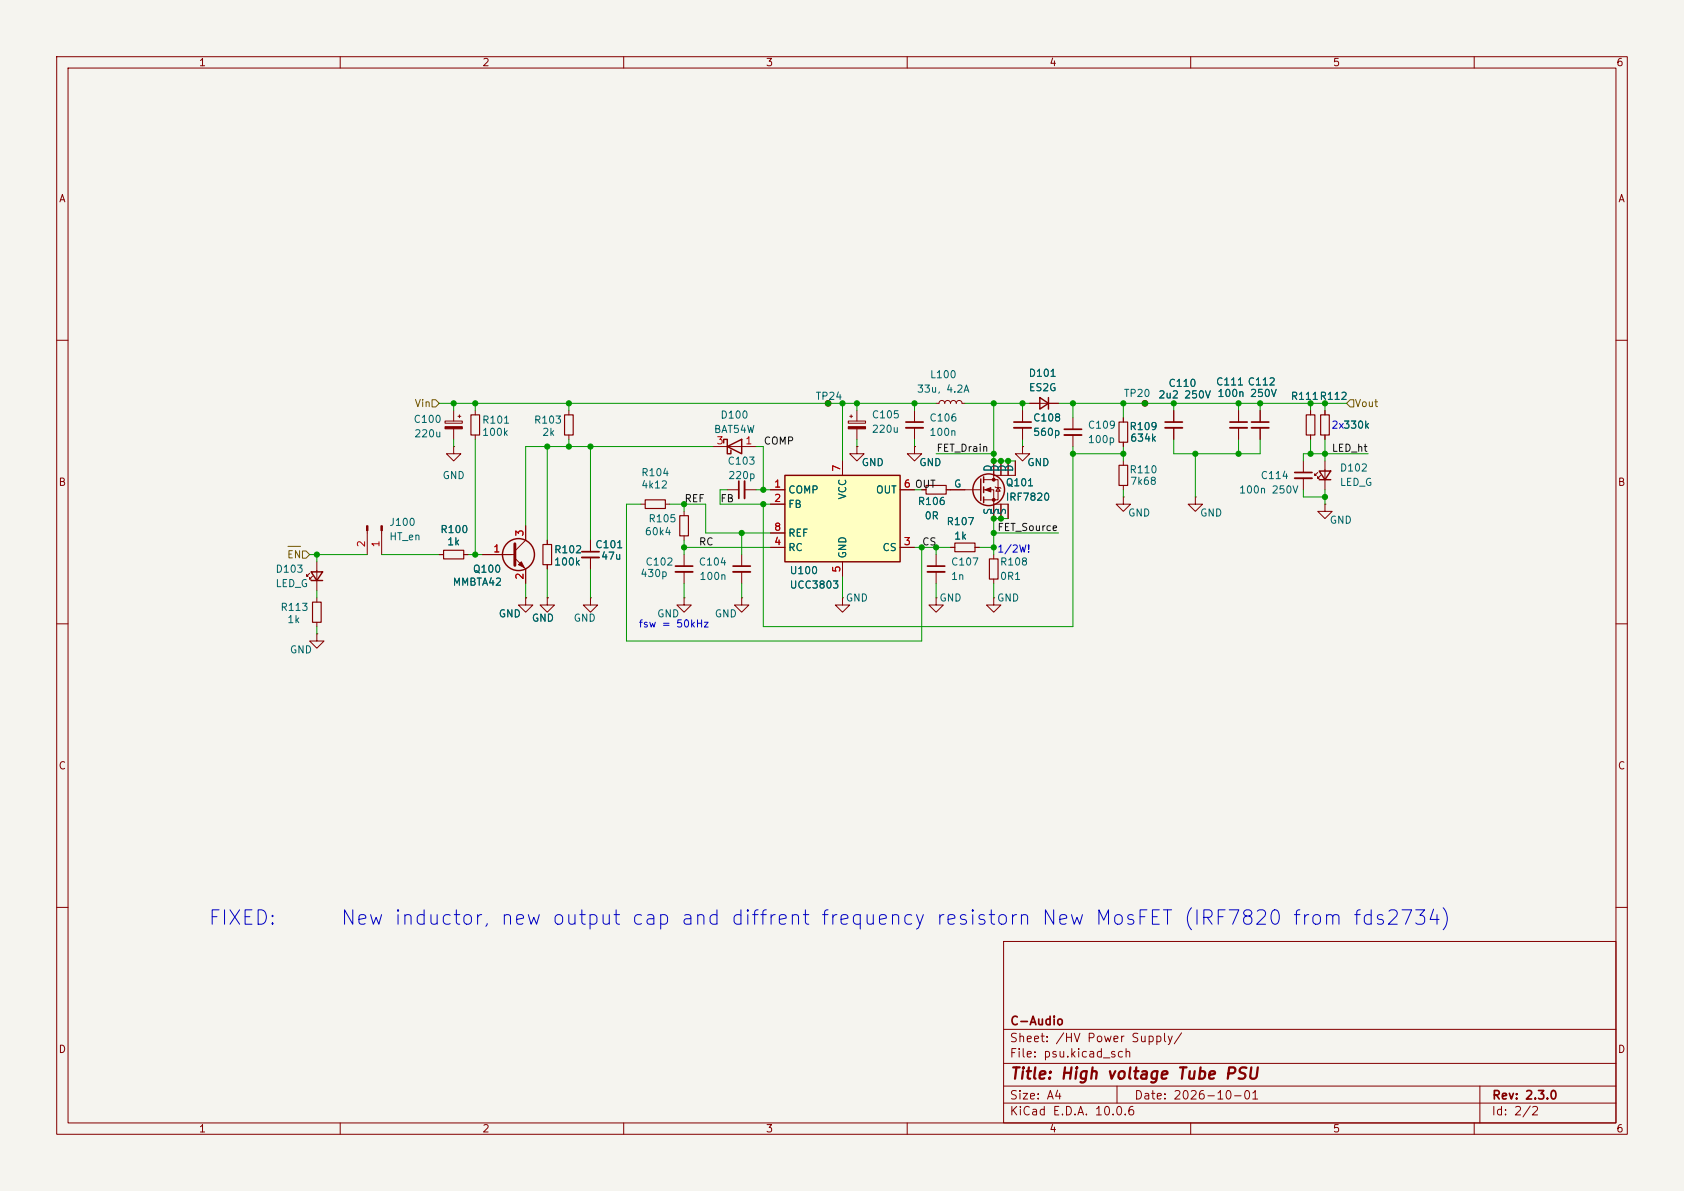
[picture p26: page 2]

C-Audio
Sheet: /HV Power Supply/
File: psu.kicad_sch
Title: High voltage Tube PSU

Size: A4 | Rev: 2.3.0
KiCad E.D.A. 10.0.6 | Id: 2/2

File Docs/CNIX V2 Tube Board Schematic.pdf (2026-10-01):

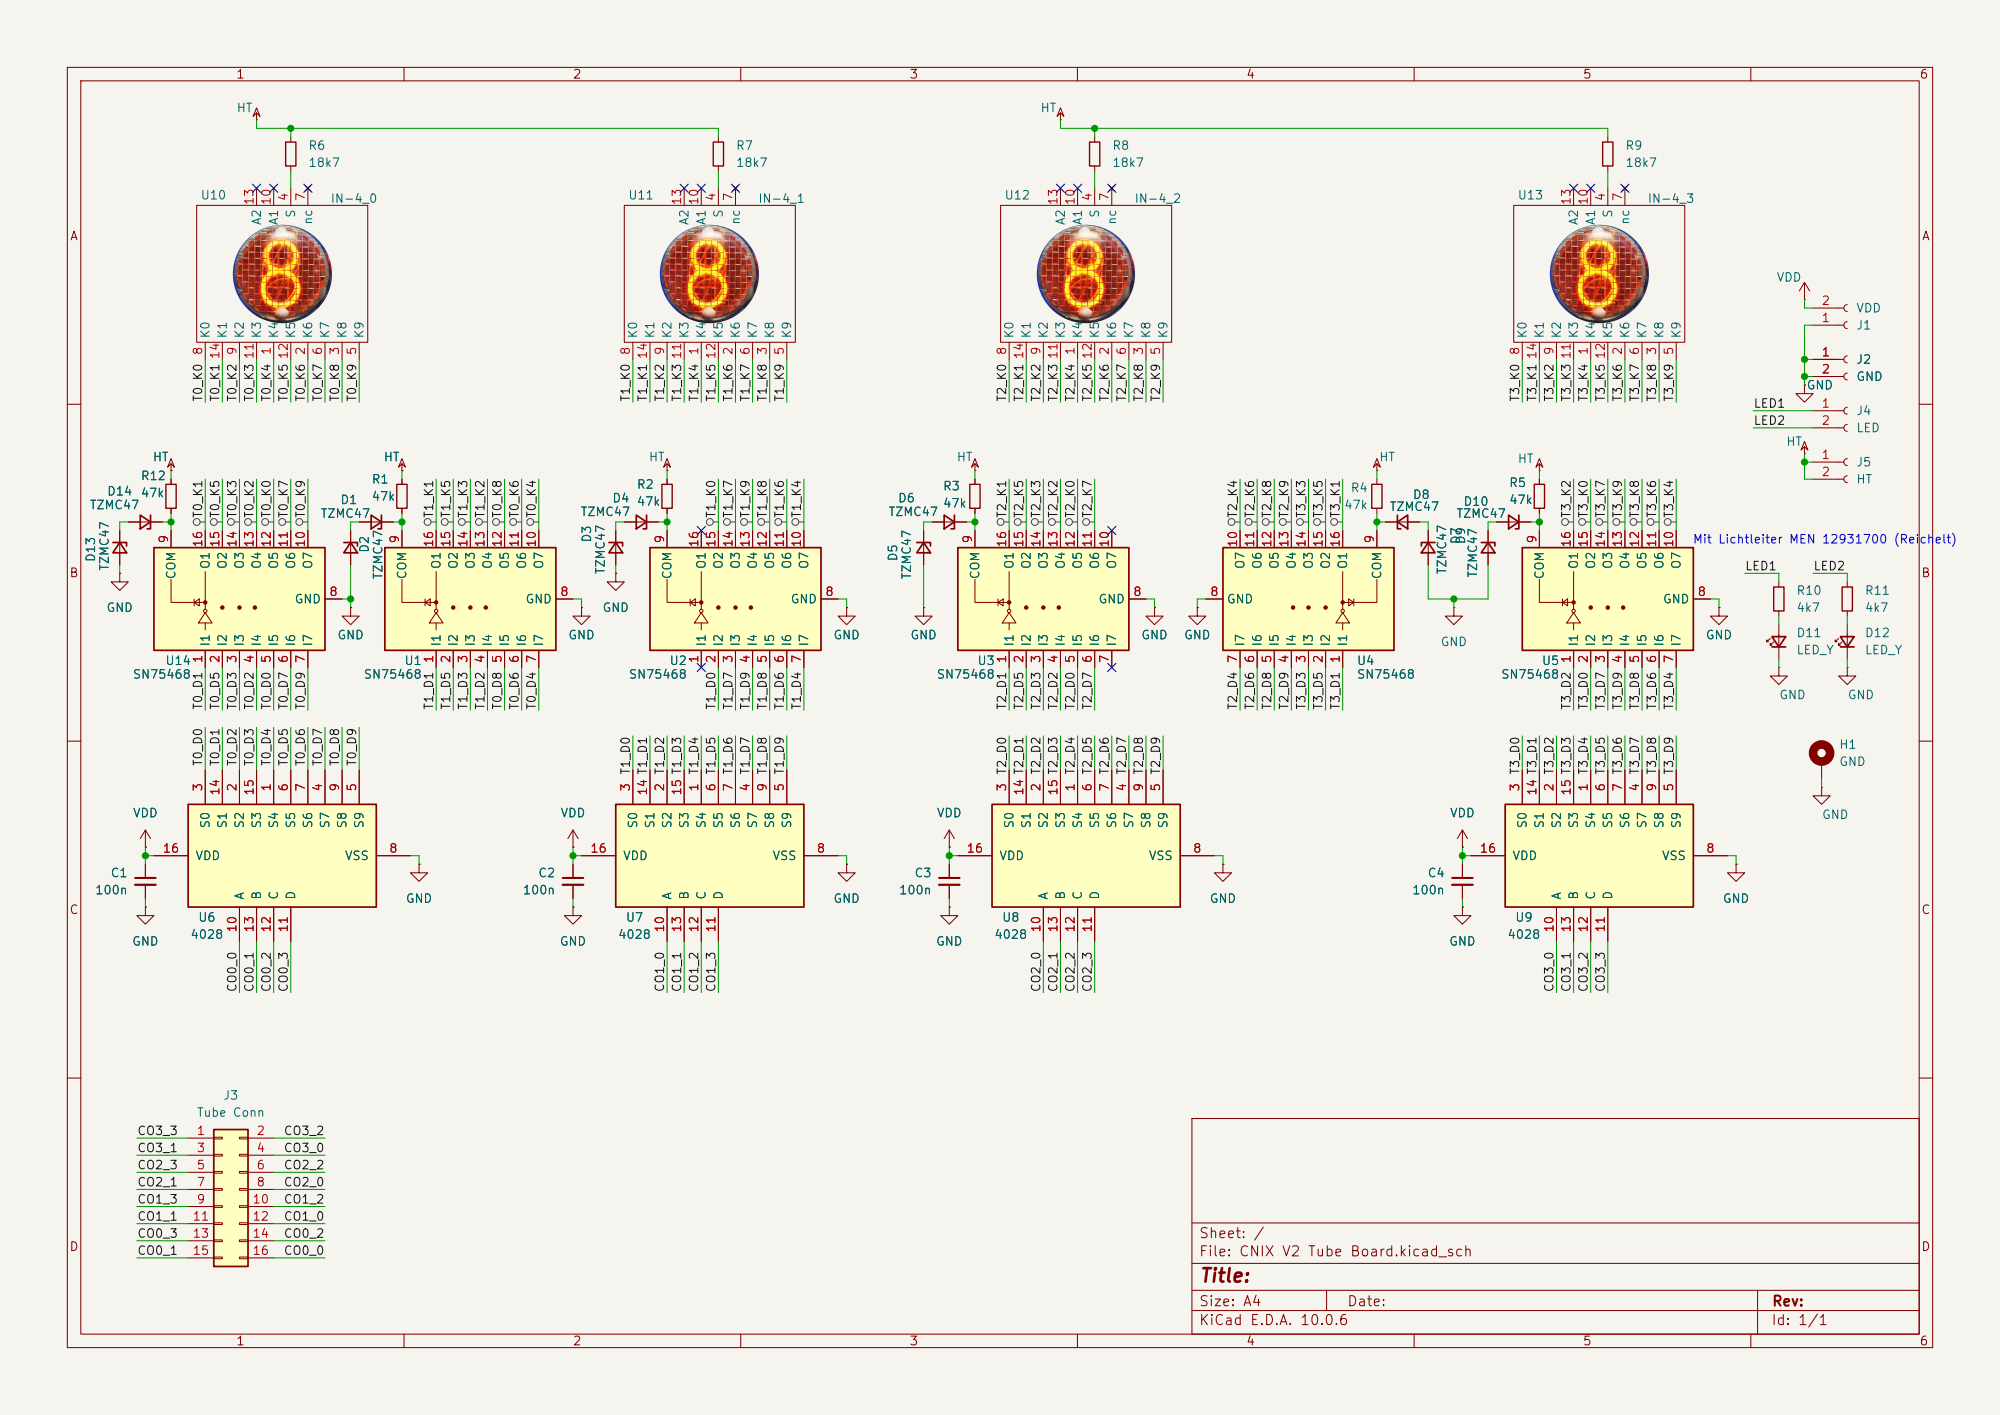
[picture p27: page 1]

File: CNIX V2 Tube Board.kicad_sch
Title:

Size: A4 | Rev:
KiCad E.D.A. 10.0.6 | Id: 1/1

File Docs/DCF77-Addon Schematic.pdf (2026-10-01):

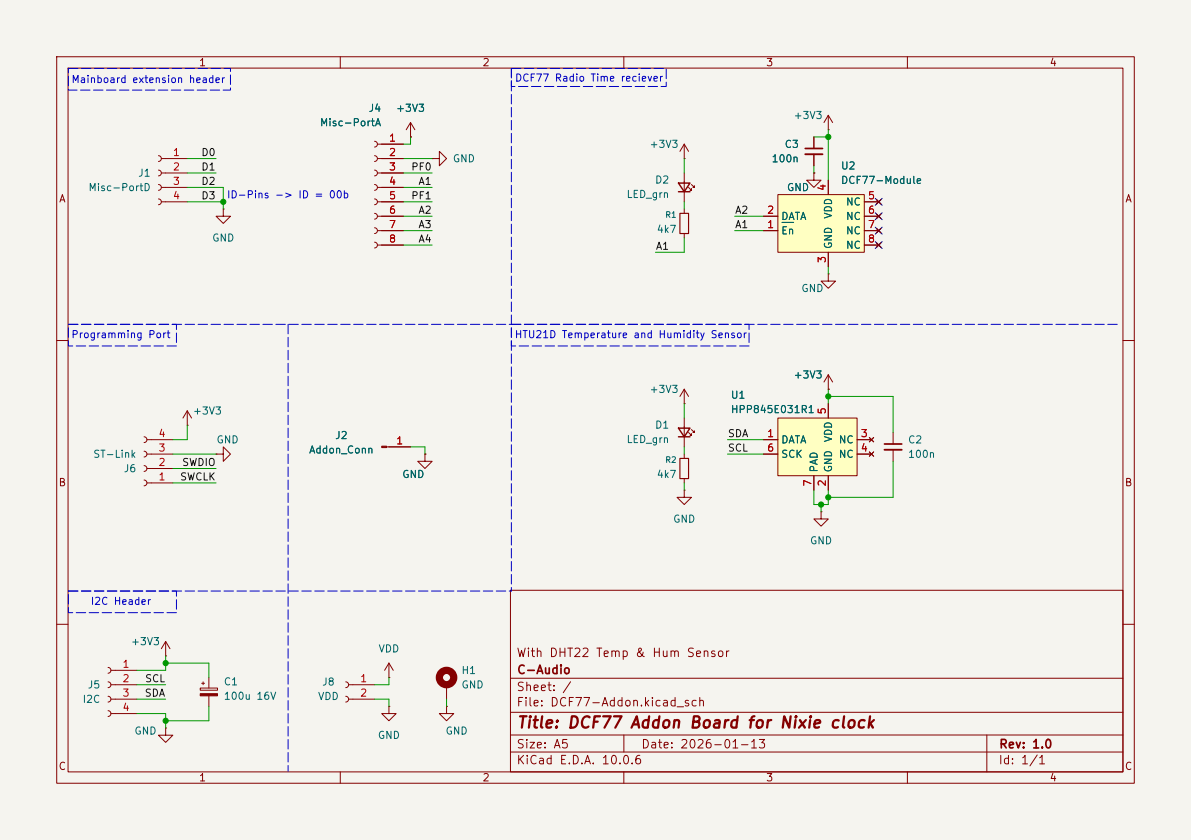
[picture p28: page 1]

4 NC 5 NC 6 NC 7 NC 8 U2DCF77-Module GND

4 NC 5 NC 6 NC 7 NC 8 GND

C-Audio
Sheet: /
File: DCF77-Addon.kicad_sch
Title: DCF77 Addon Board for Nixie clock

Size: A5 | Rev: 1.0 | C Date: 2026-01-13
KiCad E.D.A. 10.0.6 | Id: 1/1

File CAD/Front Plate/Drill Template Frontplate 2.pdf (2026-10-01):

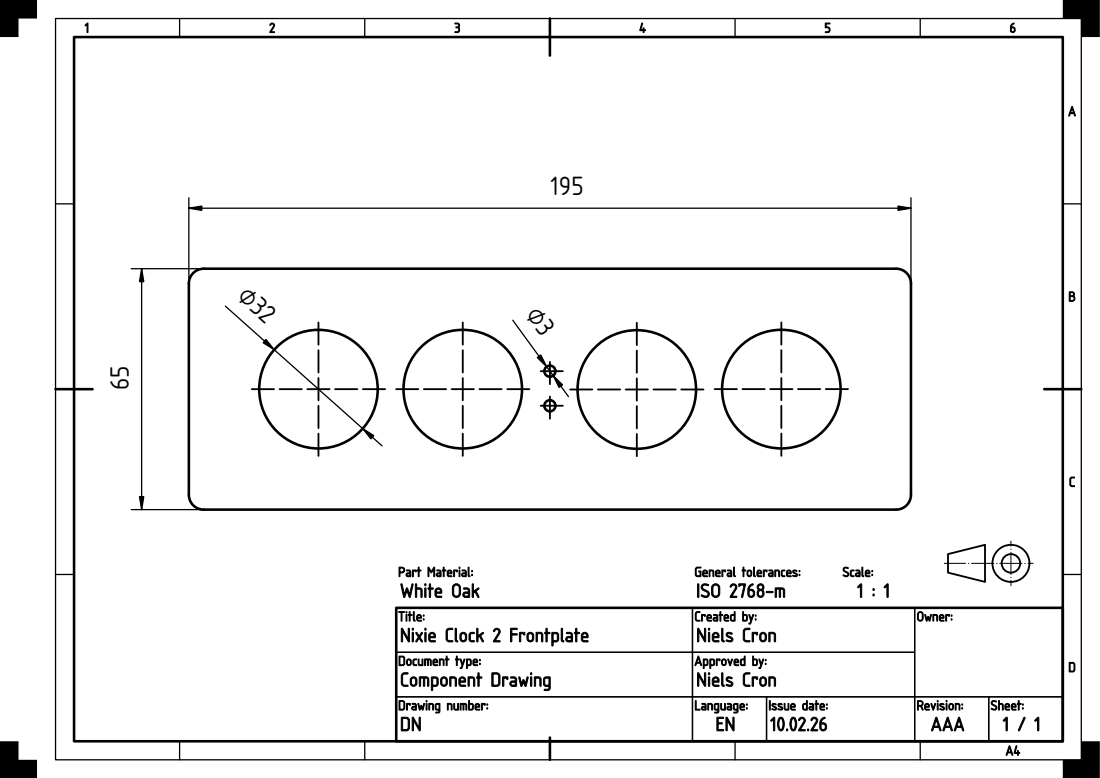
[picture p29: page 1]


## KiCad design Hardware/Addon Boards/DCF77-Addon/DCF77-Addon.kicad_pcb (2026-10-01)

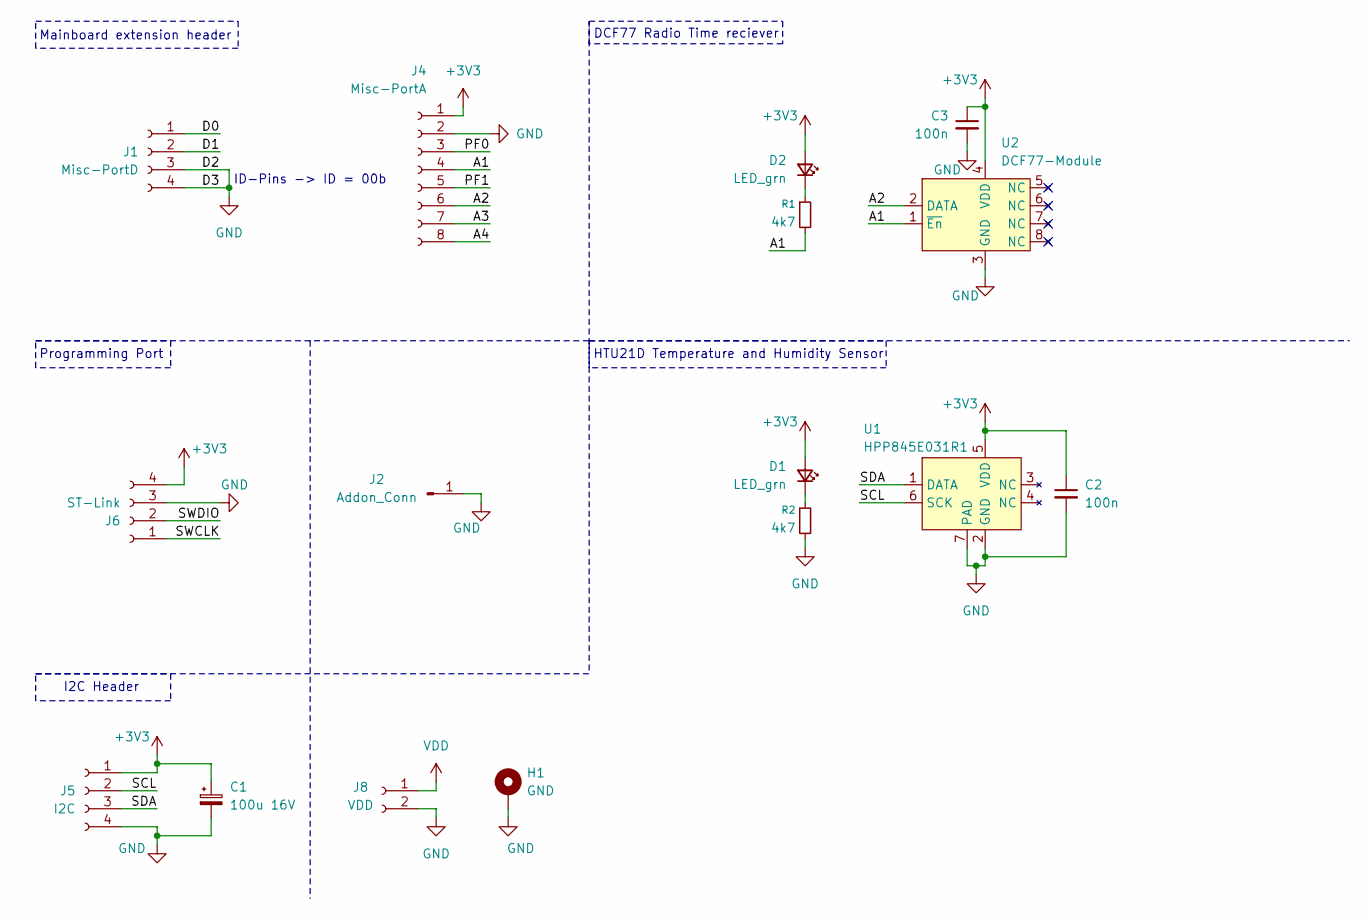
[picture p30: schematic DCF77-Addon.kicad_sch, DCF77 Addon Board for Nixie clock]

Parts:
C1: 100u 16V; CP_Elec_6.3x7.7
C2, C3: 100n; C_0805_2012Metric_Pad1.18x1.45mm_HandSolder
D1, D2: LED_grn; LED_0805_2012Metric_Pad1.15x1.40mm_HandSolder
H1: GND; TestPoint_Loop_D3.80mm_Drill2.0mm
J1: Misc-PortD; PinSocket_1x04_P2.54mm_Vertical
J2: Addon_Conn; PinHeader_1x01_P2.54mm_Vertical
J4: Misc-PortA; PinSocket_1x08_P2.54mm_Vertical
J5: I2C; PinSocket_1x04_P2.54mm_Vertical
J6: ST-Link; PinSocket_1x04_P2.54mm_Vertical
J8: VDD; PinSocket_1x02_P2.54mm_Vertical
R1, R2: 4k7; R_0805_2012Metric_Pad1.20x1.40mm_HandSolder
U1: HPP845E031R1; Maxim_TDFN-6-1EP_3x3mm_P0.95mm_EP1.5x2.3mm; Mouser Nr. 824-HPP845E031R1
U2: DCF77-Module

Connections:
+3V3: C1.1, C2.1, C3.1, D1.2 (A), D2.2 (A), J4.1, J5.1, J6.4, U1.5 (VDD), U2.4 (VDD)
/A1: J4.4, R1.2, U2.1 (~En)
/A2: J4.6, U2.2 (DATA)
/A3: J4.7
/A4: J4.8
/D0: J1.1
/D1: J1.2
/PF0: J4.3
/PF1: J4.5
/SCL: J5.2, U1.6 (SCK)
/SDA: J5.3, U1.1 (DATA)
/SWCLK: J6.1
/SWDIO: J6.2
GND: C1.2, C2.2, C3.2, H1.1 (1_1), J1.3, J1.4, J2.1 (Pin_1_1), J4.2, J5.4, J6.3, J8.2, R2.2, U1.2 (GND), U1.7 (PAD), U2.3 (GND)
unnamed: D1.1 (K), R2.1
unnamed: D2.1 (K), R1.1
VDD: J8.1

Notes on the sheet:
HTU21D Temperature and Humidity Sensor
DCF77 Radio Time reciever
Programming Port
ID-Pins -> ID = 00b
Mainboard extension header
I2C Header

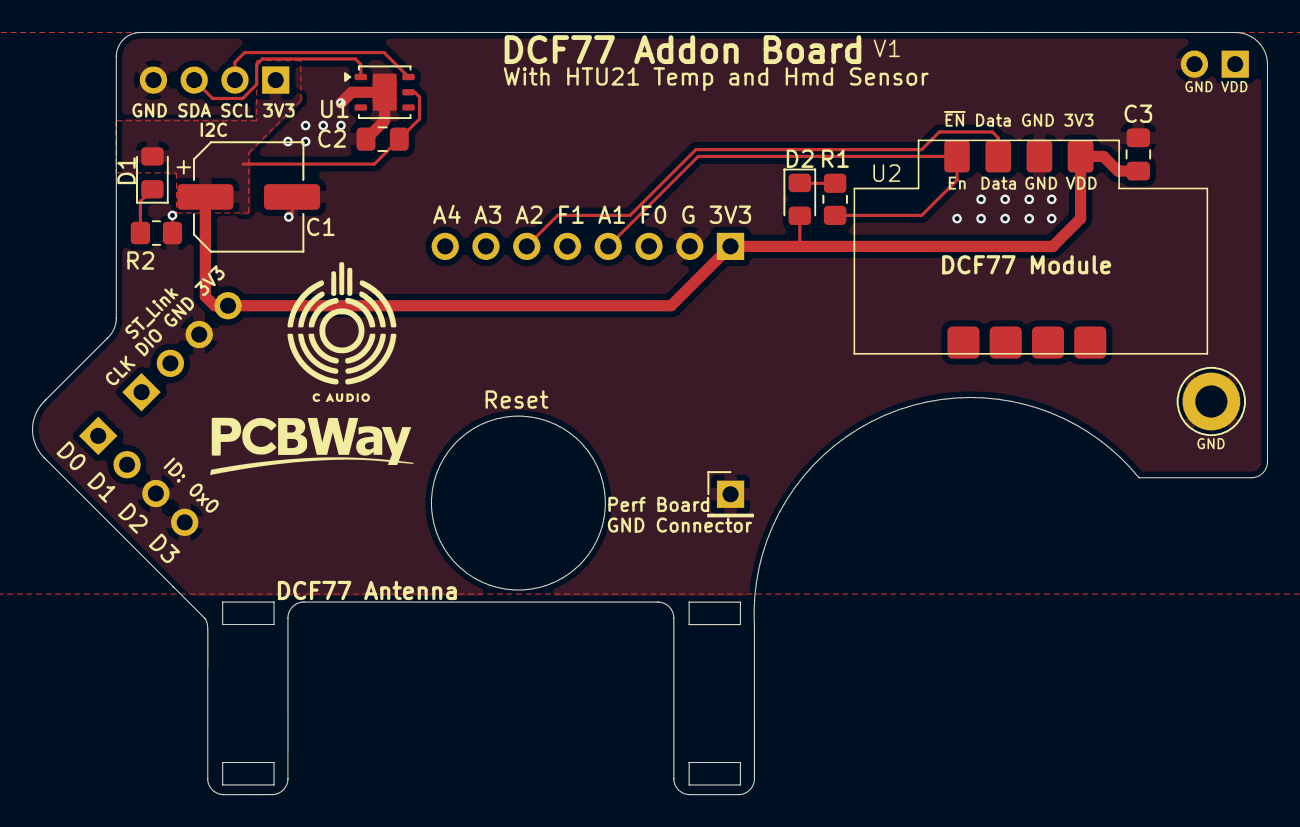
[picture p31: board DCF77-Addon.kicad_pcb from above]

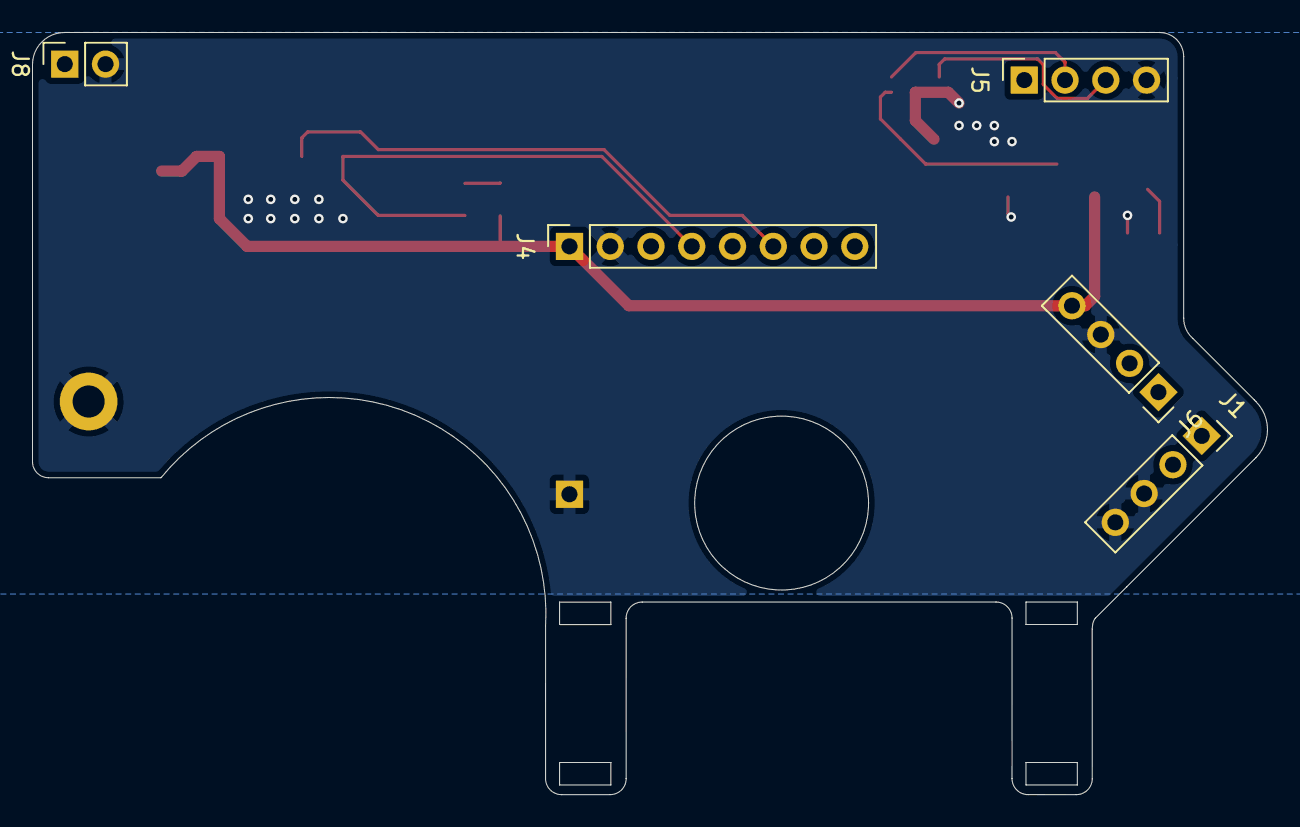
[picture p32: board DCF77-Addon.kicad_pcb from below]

Board: 2 copper layers, 77.0 x 47.5 mm, 16 parts (5 on the bottom side), 8 nets.

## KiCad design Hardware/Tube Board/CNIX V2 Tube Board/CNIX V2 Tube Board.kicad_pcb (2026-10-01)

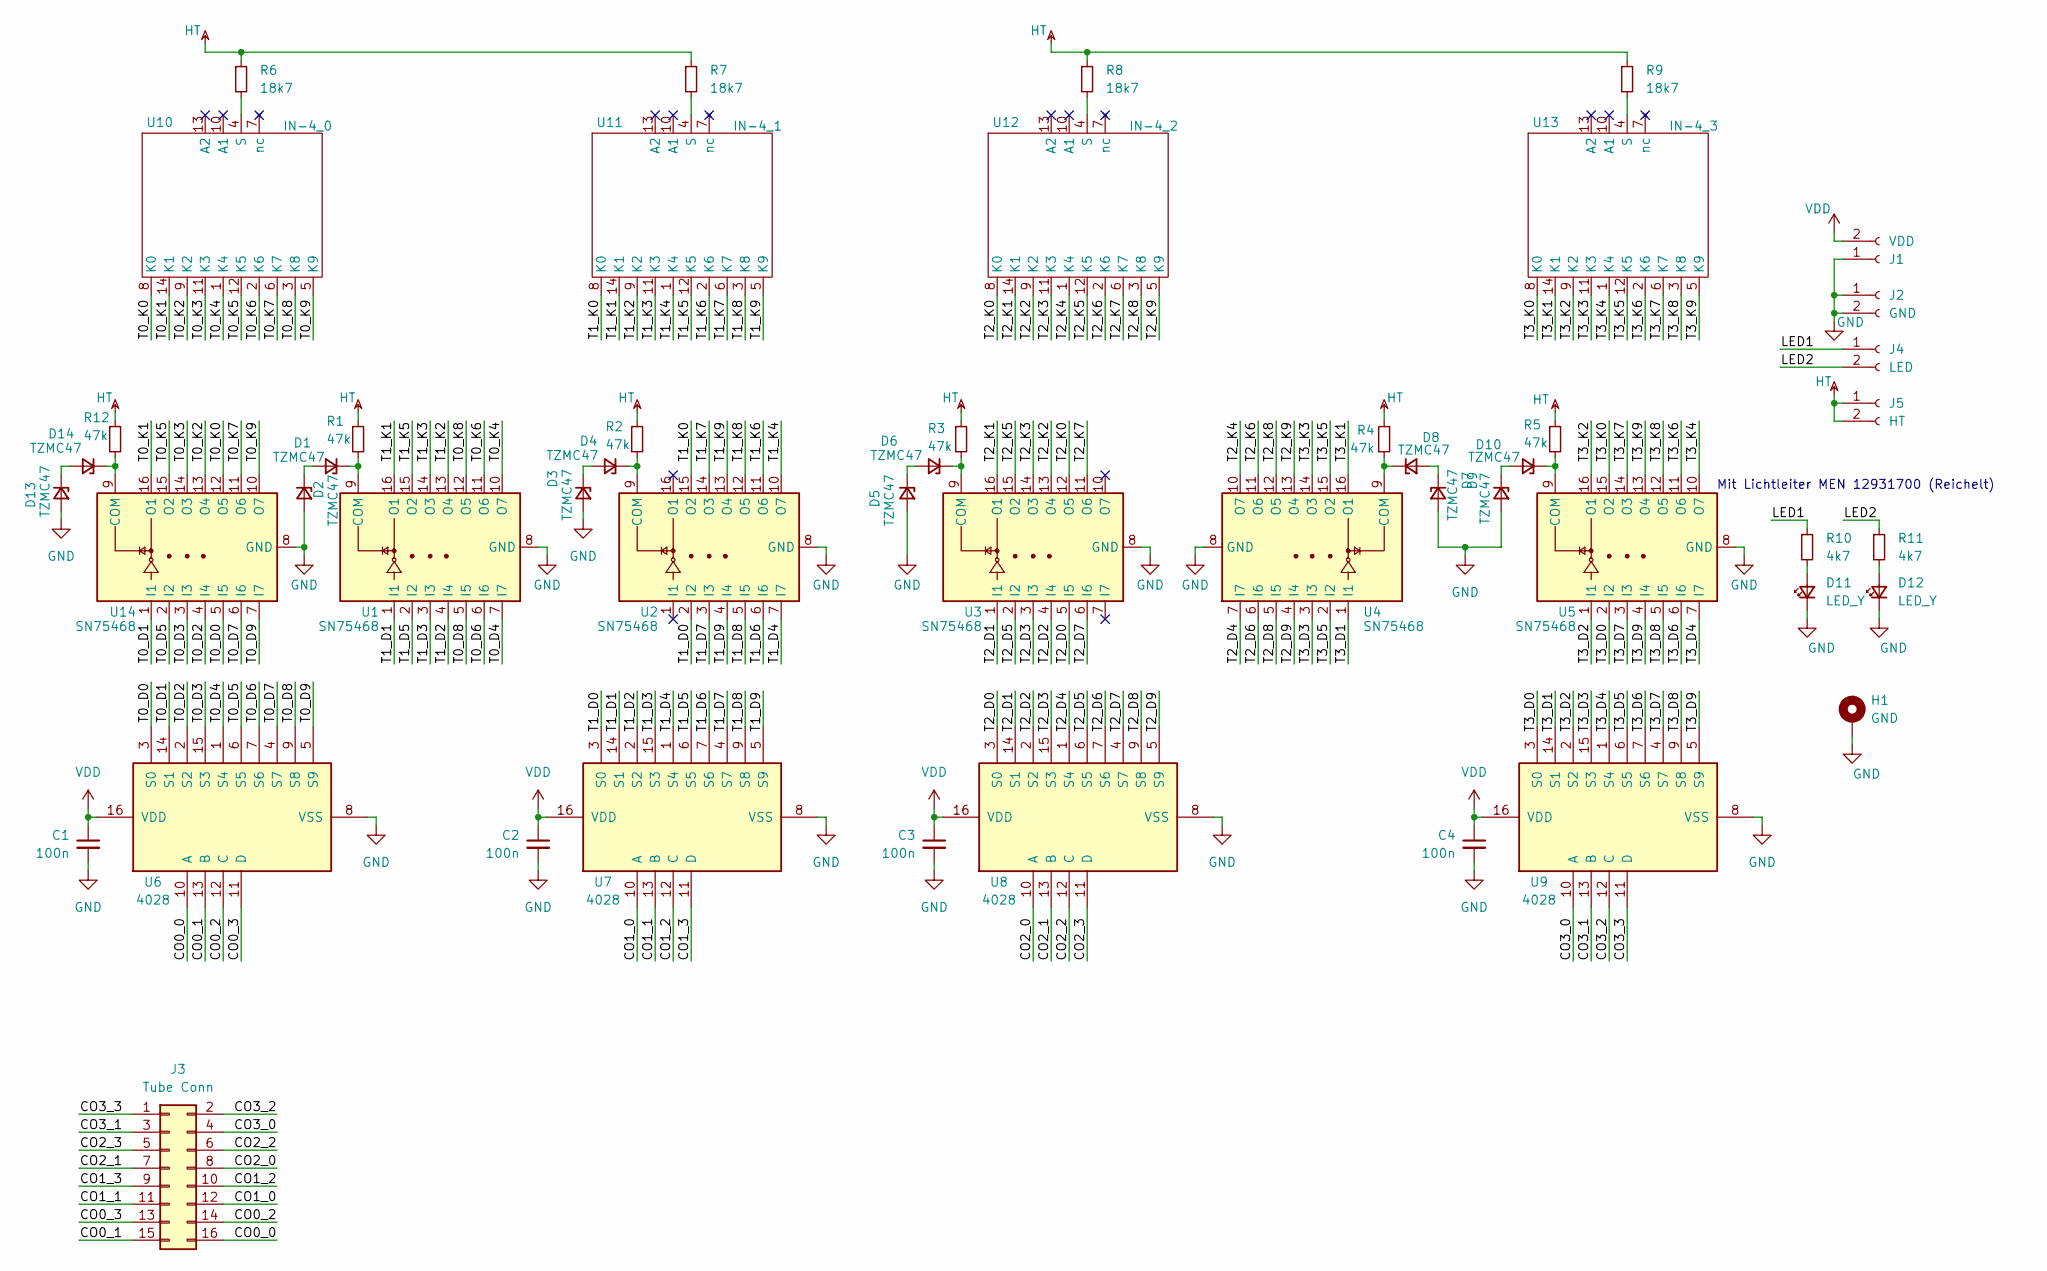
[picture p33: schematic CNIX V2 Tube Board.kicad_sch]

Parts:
C1, C2, C3, C4: 100n; C_0805_2012Metric_Pad1.18x1.45mm_HandSolder
D1, D2, D3, D4, D5, D6, D7, D8, D9, D10, D13, D14: TZMC47; D_MiniMELF; Mouser URL 78-TZMC47
D11, D12: LED_Y; LED_0805_2012Metric_Pad1.15x1.40mm_HandSolder
H1: GND; TestPoint_Plated_Hole_D3.0mm
J1: VDD; PinHeader_1x02_P2.54mm_Vertical
J2: GND; PinHeader_1x02_P2.54mm_Vertical
J3: Tube Conn; PinHeader_2x08_P2.54mm_Vertical
J4: LED; PinHeader_1x02_P2.54mm_Vertical
J5: HT; PinHeader_1x02_P2.54mm_Vertical
R1, R2, R3, R4, R5, R12: 47k; R_0805_2012Metric; Mouser Nr. 603-AC0805FR-1347KL
R6, R7, R8, R9: 18k7; R_1206_3216Metric_Pad1.30x1.75mm_HandSolder; Mouser Nr. 603-RC1206FR-0718K7L
R10, R11: 4k7; R_0805_2012Metric_Pad1.20x1.40mm_HandSolder; Mouser Nr. 603-RC0805FR-074K7P
U1, U2, U3, U4, U5, U14: SN75468; SOIC-16_3.9x9.9mm_P1.27mm; Mouser Nr. 595-SN75468DR
U6, U7, U8, U9: 4028; SOIC-16_3.9x9.9mm_P1.27mm; Mouser Nr. 595-CD4028BM96
U10: IN-4_0; IN-4
U11: IN-4_1; IN-4
U12: IN-4_2; IN-4
U13: IN-4_3; IN-4

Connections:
/CO0_0: J3.16, U6.10 (A)
/CO0_1: J3.15, U6.13 (B)
/CO0_2: J3.14, U6.12 (C)
/CO0_3: J3.13, U6.11 (D)
/CO1_0: J3.12, U7.10 (A)
/CO1_1: J3.11, U7.13 (B)
/CO1_2: J3.10, U7.12 (C)
/CO1_3: J3.9, U7.11 (D)
/CO2_0: J3.8, U8.10 (A)
/CO2_1: J3.7, U8.13 (B)
/CO2_2: J3.6, U8.12 (C)
/CO2_3: J3.5, U8.11 (D)
/CO3_0: J3.4, U9.10 (A)
/CO3_1: J3.3, U9.13 (B)
/CO3_2: J3.2, U9.12 (C)
/CO3_3: J3.1, U9.11 (D)
/LED1: J4.1, R10.1
/LED2: J4.2, R11.1
/T0_D0: U6.3 (S0), U14.5 (I5)
/T0_D1: U6.14 (S1), U14.1 (I1)
/T0_D2: U6.2 (S2), U14.4 (I4)
/T0_D3: U6.15 (S3), U14.3 (I3)
/T0_D4: U1.7 (I7), U6.1 (S4)
/T0_D5: U6.6 (S5), U14.2 (I2)
/T0_D6: U1.6 (I6), U6.7 (S6)
/T0_D7: U6.4 (S7), U14.6 (I6)
/T0_D8: U1.5 (I5), U6.9 (S8)
/T0_D9: U6.5 (S9), U14.7 (I7)
/T0_K0: U10.8 (K0), U14.12 (O5)
/T0_K1: U10.14 (K1), U14.16 (O1)
/T0_K2: U10.9 (K2), U14.13 (O4)
/T0_K3: U10.11 (K3), U14.14 (O3)
/T0_K4: U1.10 (O7), U10.1 (K4)
/T0_K5: U10.12 (K5), U14.15 (O2)
/T0_K6: U1.11 (O6), U10.2 (K6)
/T0_K7: U10.6 (K7), U14.11 (O6)
/T0_K8: U1.12 (O5), U10.3 (K8)
/T0_K9: U10.5 (K9), U14.10 (O7)
/T1_D0: U2.2 (I2), U7.3 (S0)
/T1_D1: U1.1 (I1), U7.14 (S1)
/T1_D2: U1.4 (I4), U7.2 (S2)
/T1_D3: U1.3 (I3), U7.15 (S3)
/T1_D4: U2.7 (I7), U7.1 (S4)
/T1_D5: U1.2 (I2), U7.6 (S5)
/T1_D6: U2.6 (I6), U7.7 (S6)
/T1_D7: U2.3 (I3), U7.4 (S7)
/T1_D8: U2.5 (I5), U7.9 (S8)
/T1_D9: U2.4 (I4), U7.5 (S9)
/T1_K0: U2.15 (O2), U11.8 (K0)
/T1_K1: U1.16 (O1), U11.14 (K1)
/T1_K2: U1.13 (O4), U11.9 (K2)
/T1_K3: U1.14 (O3), U11.11 (K3)
/T1_K4: U2.10 (O7), U11.1 (K4)
/T1_K5: U1.15 (O2), U11.12 (K5)
/T1_K6: U2.11 (O6), U11.2 (K6)
/T1_K7: U2.14 (O3), U11.6 (K7)
/T1_K8: U2.12 (O5), U11.3 (K8)
/T1_K9: U2.13 (O4), U11.5 (K9)
/T2_D0: U3.5 (I5), U8.3 (S0)
/T2_D1: U3.1 (I1), U8.14 (S1)
/T2_D2: U3.4 (I4), U8.2 (S2)
/T2_D3: U3.3 (I3), U8.15 (S3)
/T2_D4: U4.7 (I7), U8.1 (S4)
/T2_D5: U3.2 (I2), U8.6 (S5)
/T2_D6: U4.6 (I6), U8.7 (S6)
/T2_D7: U3.6 (I6), U8.4 (S7)
/T2_D8: U4.5 (I5), U8.9 (S8)
/T2_D9: U4.4 (I4), U8.5 (S9)
/T2_K0: U3.12 (O5), U12.8 (K0)
/T2_K1: U3.16 (O1), U12.14 (K1)
/T2_K2: U3.13 (O4), U12.9 (K2)
/T2_K3: U3.14 (O3), U12.11 (K3)
/T2_K4: U4.10 (O7), U12.1 (K4)
/T2_K5: U3.15 (O2), U12.12 (K5)
/T2_K6: U4.11 (O6), U12.2 (K6)
/T2_K7: U3.11 (O6), U12.6 (K7)
/T2_K8: U4.12 (O5), U12.3 (K8)
/T2_K9: U4.13 (O4), U12.5 (K9)
/T3_D0: U5.2 (I2), U9.3 (S0)
/T3_D1: U4.1 (I1), U9.14 (S1)
/T3_D2: U5.1 (I1), U9.2 (S2)
/T3_D3: U4.3 (I3), U9.15 (S3)
/T3_D4: U5.7 (I7), U9.1 (S4)
/T3_D5: U4.2 (I2), U9.6 (S5)
/T3_D6: U5.6 (I6), U9.7 (S6)
/T3_D7: U5.3 (I3), U9.4 (S7)
/T3_D8: U5.5 (I5), U9.9 (S8)
/T3_D9: U5.4 (I4), U9.5 (S9)
/T3_K0: U5.15 (O2), U13.8 (K0)
/T3_K1: U4.16 (O1), U13.14 (K1)
/T3_K2: U5.16 (O1), U13.9 (K2)
/T3_K3: U4.14 (O3), U13.11 (K3)
/T3_K4: U5.10 (O7), U13.1 (K4)
/T3_K5: U4.15 (O2), U13.12 (K5)
/T3_K6: U5.11 (O6), U13.2 (K6)
/T3_K7: U5.14 (O3), U13.6 (K7)
/T3_K8: U5.12 (O5), U13.3 (K8)
/T3_K9: U5.13 (O4), U13.5 (K9)
GND: C1.2, C2.2, C3.2, C4.2, D2.2 (A), D3.2 (A), D5.2 (A), D7.2 (A), D9.2 (A), D11.1 (K), D12.1 (K), D13.2 (A), H1.1, J1.1, J2.1, J2.2, U1.8 (GND), U2.8 (GND), U3.8 (GND), U4.8 (GND), U5.8 (GND), U6.8 (VSS), U7.8 (VSS), U8.8 (VSS), U9.8 (VSS), U14.8 (GND)
HT: J5.1, J5.2, R1.1, R2.1, R3.1, R4.1, R5.1, R6.1, R7.1, R8.1, R9.1, R12.1
unnamed: D1.2 (A), D2.1 (K)
unnamed: D1.1 (K), R1.2, U1.9 (COM)
unnamed: D3.1 (K), D4.2 (A)
unnamed: D4.1 (K), R2.2, U2.9 (COM)
unnamed: D5.1 (K), D6.2 (A)
unnamed: D6.1 (K), R3.2, U3.9 (COM)
unnamed: D7.1 (K), D8.2 (A)
unnamed: D8.1 (K), R4.2, U4.9 (COM)
unnamed: D9.1 (K), D10.2 (A)
unnamed: D10.1 (K), R5.2, U5.9 (COM)
unnamed: D11.2 (A), R10.2
unnamed: D12.2 (A), R11.2
unnamed: D13.1 (K), D14.2 (A)
unnamed: D14.1 (K), R12.2, U14.9 (COM)
unnamed: R6.2, U10.4 (S)
unnamed: R7.2, U11.4 (S)
unnamed: R8.2, U12.4 (S)
unnamed: R9.2, U13.4 (S)
VDD: C1.1, C2.1, C3.1, C4.1, J1.2, U6.16 (VDD), U7.16 (VDD), U8.16 (VDD), U9.16 (VDD)

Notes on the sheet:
Mit Lichtleiter MEN 12931700 (Reichelt)

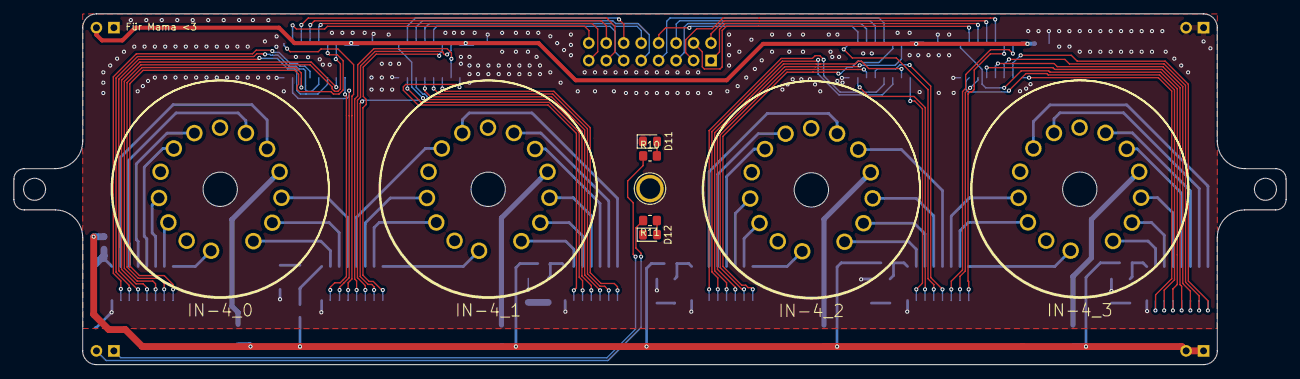
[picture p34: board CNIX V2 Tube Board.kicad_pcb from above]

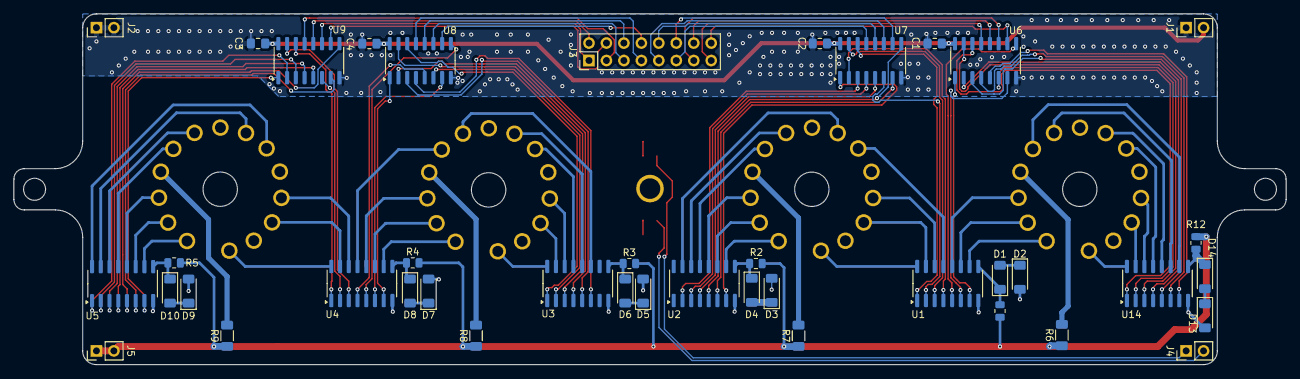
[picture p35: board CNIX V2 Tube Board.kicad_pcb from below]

Board: 2 copper layers, 185.0 x 51.0 mm, 50 parts (41 on the bottom side), 119 nets.

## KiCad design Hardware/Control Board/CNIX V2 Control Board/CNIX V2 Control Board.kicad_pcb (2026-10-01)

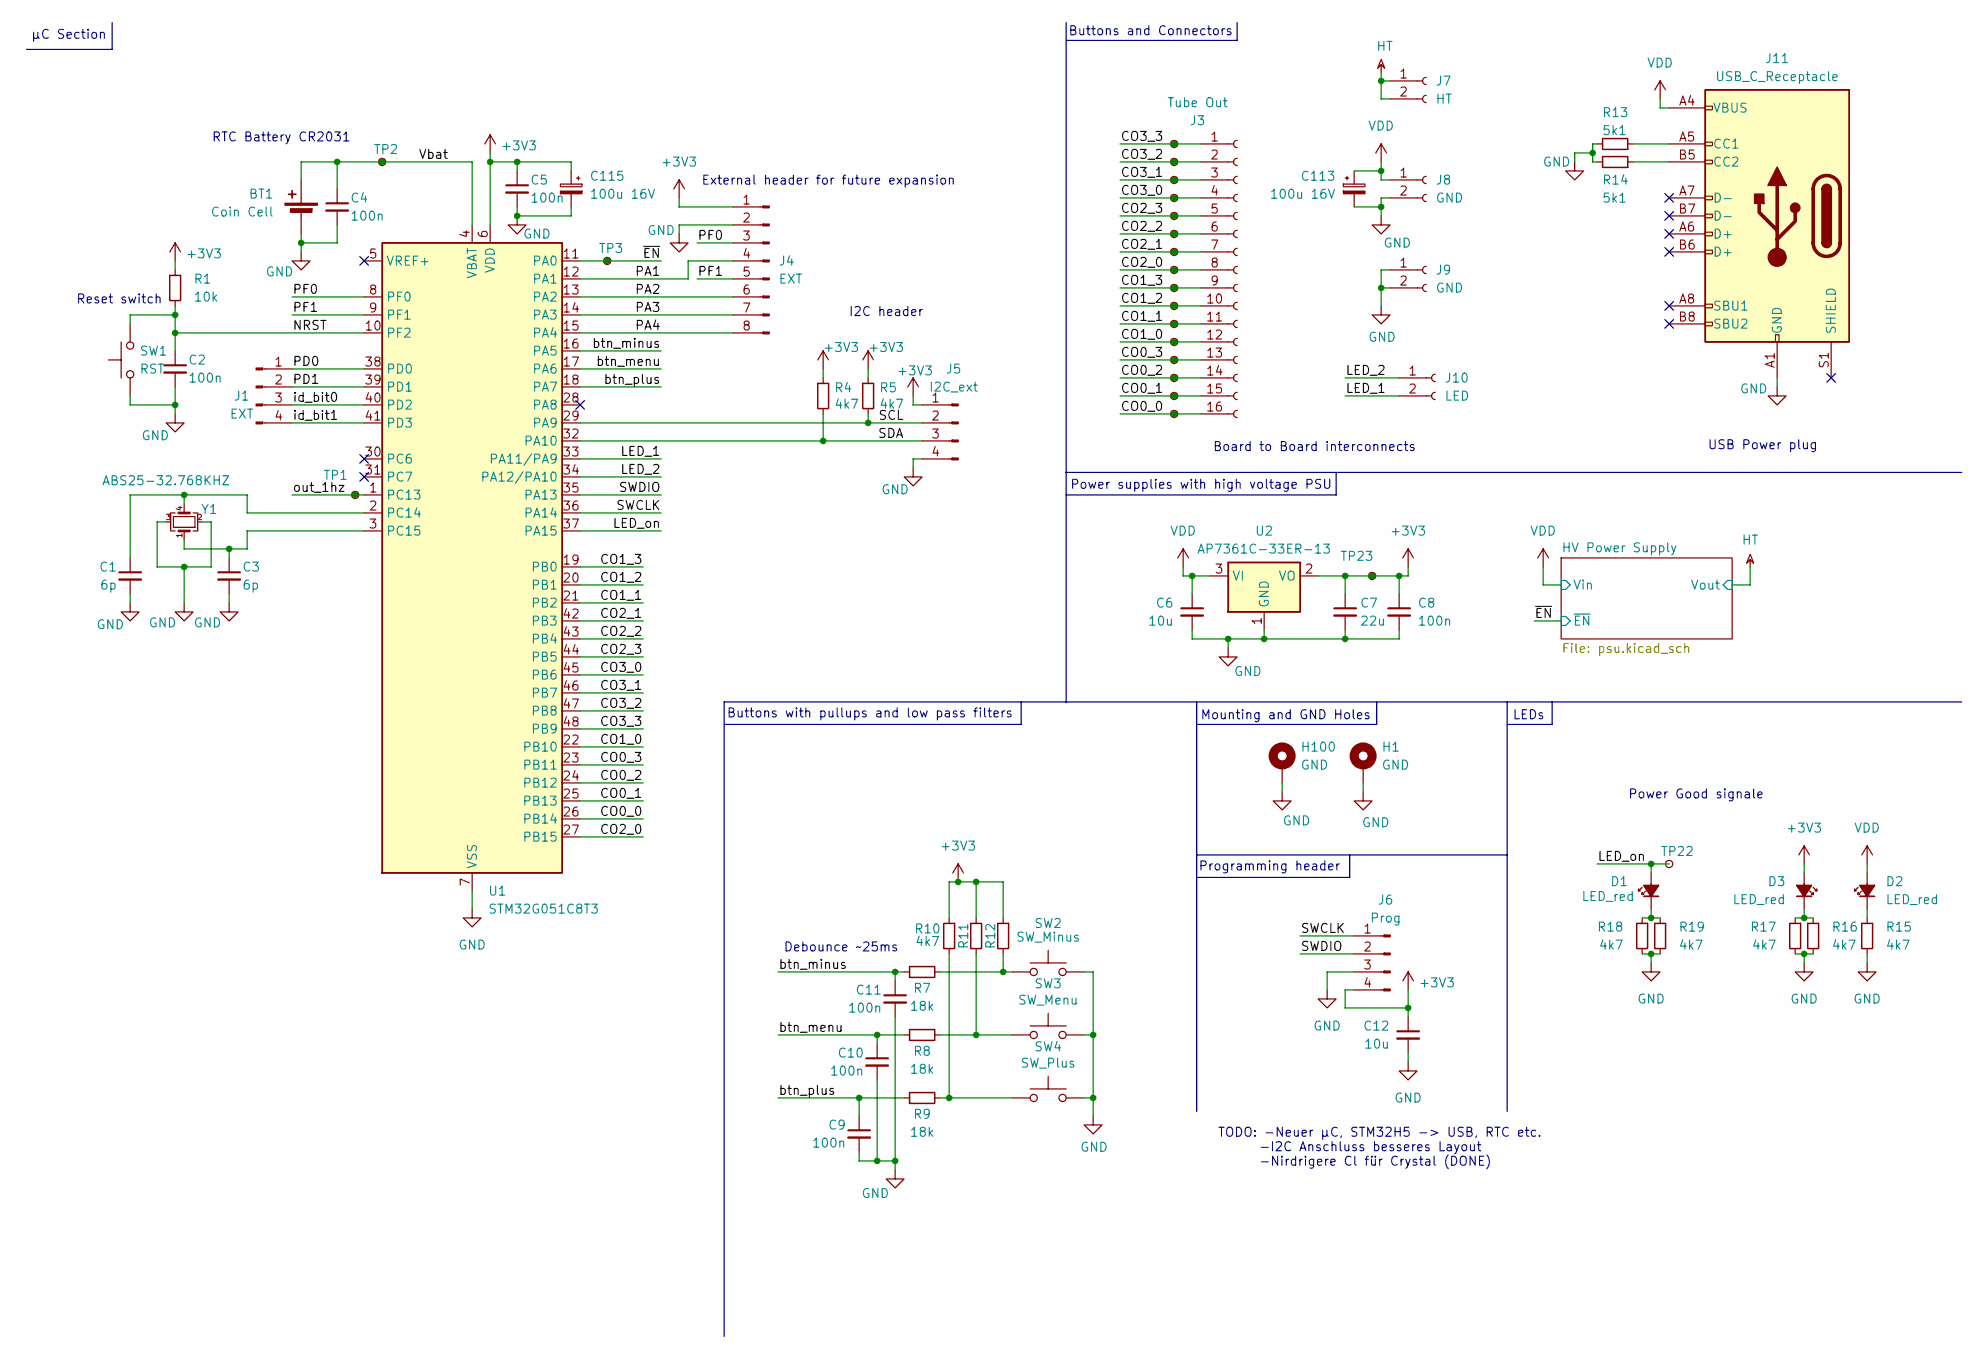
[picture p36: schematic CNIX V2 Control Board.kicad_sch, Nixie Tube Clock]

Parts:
BT1: Coin Cell; BatteryHolder_Renata_SMTU2032-LF_1x2032; Mouser Nr. 614-SMTU2032-LF.TR
C1, C3: 6p; C_0805_2012Metric_Pad1.18x1.45mm_HandSolder; Mouser Nr. 80-C0805C180K5HACTU
C2, C4, C5, C8, C9, C10, C11: 100n; C_0805_2012Metric_Pad1.18x1.45mm_HandSolder
C6, C12: 10u; C_0805_2012Metric_Pad1.18x1.45mm_HandSolder; Mouser Nr. 187-CL21B106KPQNNNE
C7: 22u; C_0805_2012Metric_Pad1.18x1.45mm_HandSolder; Mouser Nr. 187-CL21A226MQQNNNG
C113, C115: 100u 16V; CP_Elec_6.3x7.7; Mouser Nr. 710-865080343009
D1, D2, D3: LED_red; LED_0805_2012Metric_Pad1.15x1.40mm_HandSolder
H1: GND; TestPoint_Loop_D3.80mm_Drill2.0mm
H100: GND; TestPoint_Plated_Hole_D3.0mm
J1: EXT; PinHeader_1x04_P2.54mm_Vertical
J3: Tube Out; PinSocket_2x08_P2.54mm_Vertical
J4: EXT; PinHeader_1x08_P2.54mm_Vertical
J5: I2C_ext; PinHeader_1x04_P2.54mm_Vertical
J6: Prog; PinHeader_1x04_P2.54mm_Vertical
J7: HT; PinSocket_1x02_P2.54mm_Vertical
J8, J9: GND; PinSocket_1x02_P2.54mm_Vertical
J10: LED; PinSocket_1x02_P2.54mm_Vertical
J11: USB_C_Receptacle; USB_C_Receptacle_GCT_USB4085
R1: 10k; R_0805_2012Metric_Pad1.20x1.40mm_HandSolder
R4, R5, R10, R11, R12, R15, R16, R17, R18, R19: 4k7; R_0805_2012Metric_Pad1.20x1.40mm_HandSolder; Mouser Nr. 603-RC0805FR-074K7P
R7, R8, R9: 18k; R_0805_2012Metric_Pad1.20x1.40mm_HandSolder; Mouser Nr. 603-RC0805FR-074K7P
R13, R14: 5k1; R_0805_2012Metric_Pad1.20x1.40mm_HandSolder; Mouser Nr. 652-CR0805FX-5101ELF
SW1: RST; SW_SPST_Omron_B3FS-100xP
SW2: SW_Minus; SW_Tactile_SPST_Angled_PTS645Vx31-2LFS
SW3: SW_Menu; SW_Tactile_SPST_Angled_PTS645Vx31-2LFS
SW4: SW_Plus; SW_Tactile_SPST_Angled_PTS645Vx31-2LFS
TP1, TP2, TP3, TP22, TP23: TestPoint_Small; TestPoint_Pad_D1.5mm
TP4, TP5, TP6, TP7, TP8, TP9, TP10, TP11, TP12, TP13, TP14, TP15, TP16, TP17, TP18, TP19: TestPoint_Small; TestPoint_THTPad_D1.0mm_Drill0.5mm
U1: STM32G051C8T3; LQFP-48_7x7mm_P0.5mm; Mouser Nr. 511-STM32G051C8T3
U2: AP7361C-33ER-13; SOT-223-3_TabPin2; Mouser-Nr. 621-AP7361C-33ER-13
Y1: ABS25-32.768KHZ; Crystal_SMD_Abracon_ABS25-4Pin_8.0x3.8mm; Mouser Nr. 815-ABS25-32.7-6-1-T

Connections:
+3V3: C5.1, C7.1, C8.1, C12.1, C115.1, D3.2 (A), J4.1, J5.1, J6.4, R1.1, R4.1, R5.1, R10.2, R11.1, R12.1, TP23.1, U1.6 (VDD), U2.2 (VO)
/CO0_0: J3.16, TP19.1, U1.26 (PB14)
/CO0_1: J3.15, TP18.1, U1.25 (PB13)
/CO0_2: J3.14, TP17.1, U1.24 (PB12)
/CO0_3: J3.13, TP16.1, U1.23 (PB11)
/CO1_0: J3.12, TP15.1, U1.22 (PB10)
/CO1_1: J3.11, TP14.1, U1.21 (PB2)
/CO1_2: J3.10, TP13.1, U1.20 (PB1)
/CO1_3: J3.9, TP12.1, U1.19 (PB0)
/CO2_0: J3.8, TP11.1, U1.27 (PB15)
/CO2_1: J3.7, TP10.1, U1.42 (PB3)
/CO2_2: J3.6, TP9.1, U1.43 (PB4)
/CO2_3: J3.5, TP8.1, U1.44 (PB5)
/CO3_0: J3.4, TP7.1, U1.45 (PB6)
/CO3_1: J3.3, TP6.1, U1.46 (PB7)
/CO3_2: J3.2, TP5.1, U1.47 (PB8)
/CO3_3: J3.1, TP4.1, U1.48 (PB9)
/LED_1: J10.2, U1.33 (PA11/PA9)
/LED_2: J10.1, U1.34 (PA12/PA10)
/LED_on: D1.2 (A), TP22.1, U1.37 (PA15)
/NRST: C2.1, R1.2, SW1.2, U1.10 (PF2)
/PA1: J4.4, U1.12 (PA1)
/PA2: J4.6, U1.13 (PA2)
/PA3: J4.7, U1.14 (PA3)
/PA4: J4.8, U1.15 (PA4)
/PD0: J1.1, U1.38 (PD0)
/PD1: J1.2, U1.39 (PD1)
/PF0: J4.3, U1.8 (PF0)
/PF1: J4.5, U1.9 (PF1)
/SCL: J5.2, R5.2, U1.29 (PA9)
/SDA: J5.3, R4.2, U1.32 (PA10)
/SWCLK: J6.1, U1.36 (PA14)
/SWDIO: J6.2, U1.35 (PA13)
/Vbat: BT1.1 (+), C4.1, TP2.1, U1.4 (VBAT)
/btn_menu: C10.1, R8.1, U1.17 (PA6)
/btn_minus: C11.1, R7.1, U1.16 (PA5)
/btn_plus: C9.1, R9.1, U1.18 (PA7)
/id_bit0: J1.3, U1.40 (PD2)
/id_bit1: J1.4, U1.41 (PD3)
/out_1hz: TP1.1, U1.1 (PC13)
/~EN: TP3.1, U1.11 (PA0); also elsewhere on the board
GND: BT1.2 (-), C1.2, C2.2, C3.2, C4.2, C5.2, C6.2, C7.2, C8.2, C9.2, C10.2, C11.2, C12.2, C113.2, C115.2, H1.1, H100.1, J4.2, J5.4, J6.3, J8.2, J9.1, J9.2, J11.A1 (GND), J11.A12 (GND), J11.B1 (GND), J11.B12 (GND), R13.2, R14.2, R15.2, R16.2, R17.2, R18.2, R19.2, SW1.1, SW2.2, SW3.2, SW4.2, U1.7 (VSS), U2.1 (GND), Y1.2, Y1.3; also elsewhere on the board
HT: J7.1, J7.2; also elsewhere on the board
unnamed 52: D1.1 (K), R18.1, R19.1; also elsewhere on the board
unnamed: D2.1 (K), R15.1
unnamed: D3.1 (K), R16.1, R17.1
unnamed: J11.A5 (CC1), R13.1
unnamed: J11.B5 (CC2), R14.1
unnamed: R9.2, R10.1, SW4.1
unnamed: R8.2, R11.2, SW3.1
unnamed: R7.2, R12.2, SW2.1
unnamed: C1.1, U1.2 (PC14), Y1.4
unnamed: C3.1, U1.3 (PC15), Y1.1
VDD: C6.1, C113.1, D2.2 (A), J8.1, J11.A4 (VBUS), J11.A9 (VBUS), J11.B4 (VBUS), J11.B9 (VBUS), U2.3 (VI); also elsewhere on the board

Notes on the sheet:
Board to Board interconnects
RTC Battery CR2031
µC Section
Programming header
External header for future expansion
Mounting and GND Holes
TODO: -Neuer µC, STM32H5 -> USB, RTC etc. -I2C Anschluss besseres Layout -Nirdrigere Cl für Crystal (DONE)
Power supplies with high voltage PSU
Buttons with pullups and low pass filters
Power Good signale
I2C header
USB Power plug
Debounce ~25ms
Reset switch
LEDs
Buttons and Connectors

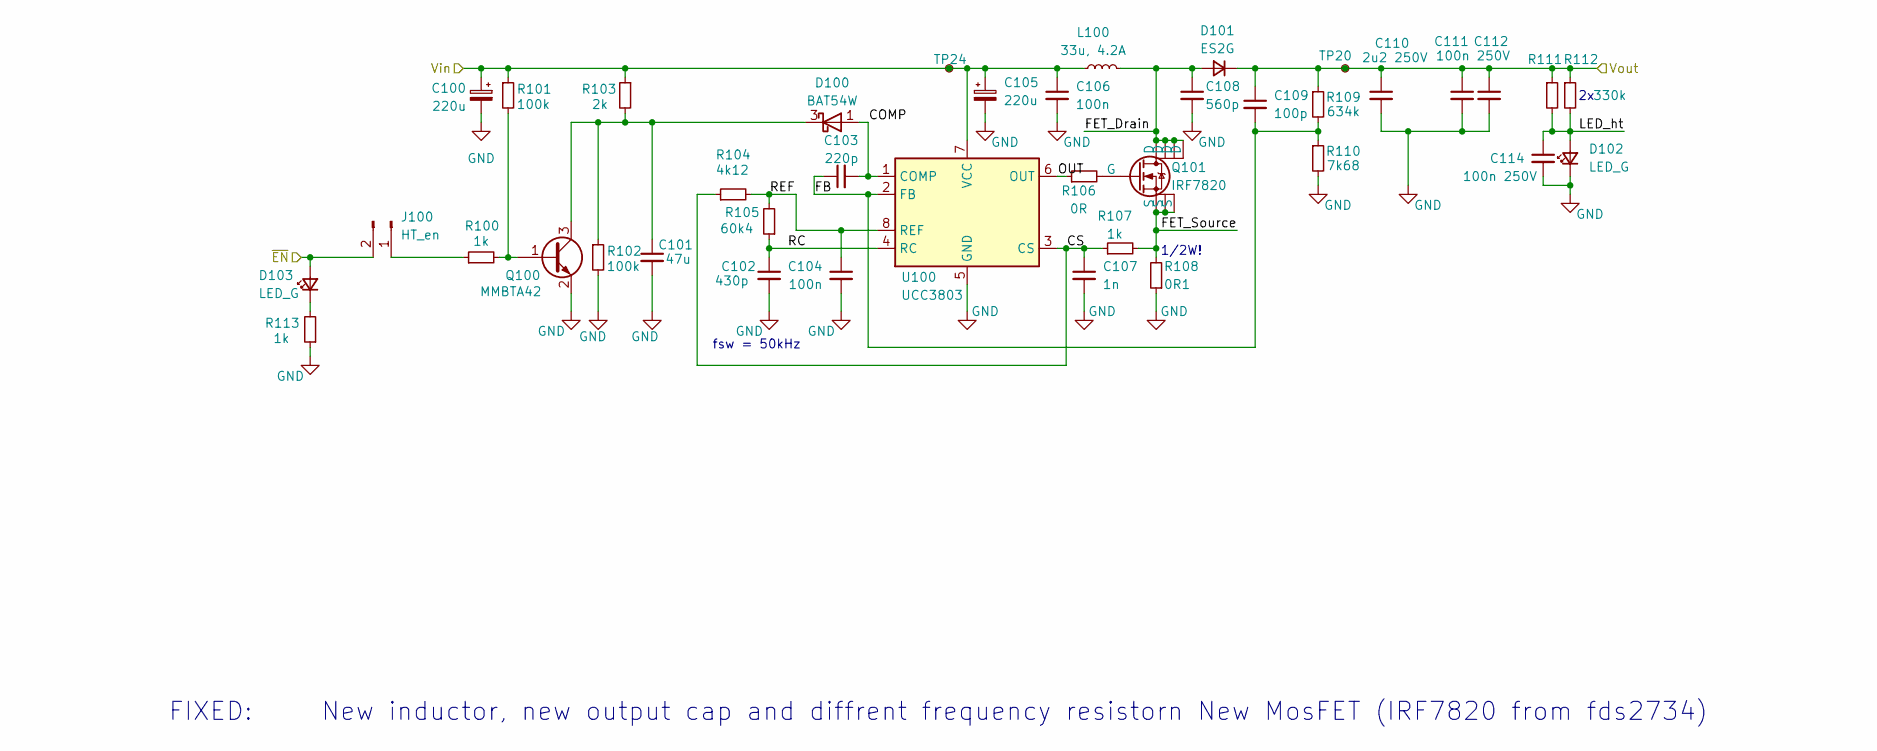
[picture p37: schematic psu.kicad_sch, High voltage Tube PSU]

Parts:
C100, C105: 220u; CP_Elec_8x10; Mouser Nr. 647-UUX1E221MNL6GS
C101: 47u; C_0805_2012Metric_Pad1.18x1.45mm_HandSolder; Mouser Nr. 187-CL21A476MRYNNNE
C102: 430p; C_0805_2012Metric_Pad1.18x1.45mm_HandSolder; Mouser Nr. 80-C0805C431J5G
C103: 220p; C_0805_2012Metric_Pad1.18x1.45mm_HandSolder; Mouser Nr. 710-885012207082
C104, C106: 100n; C_0805_2012Metric_Pad1.18x1.45mm_HandSolder
C107: 1n; C_0805_2012Metric_Pad1.18x1.45mm_HandSolder; Mouser Nr. 187-CL21B102KBANNNC
C108: 560p; C_0805_2012Metric_Pad1.18x1.45mm_HandSolder; Mouser Nr. 80-C0805C561K2R
C109: 100p; C_0805_2012Metric_Pad1.18x1.45mm_HandSolder; Mouser Nr. 581-08052C101K
C110: 2u2 250V; C_2220_5750Metric_Pad1.97x5.40mm_HandSolder; Mouser Nr. 710-885342214003
C111: 100nf 250V; C_0805_2012Metric_Pad1.18x1.45mm_HandSolder; Mouser Nr. 810-CGA4J3X7T2E104MA
C112, C114: 100n 250V; C_0805_2012Metric_Pad1.18x1.45mm_HandSolder; Mouser Nr. 810-CGA4J3X7T2E104MA
D100: BAT54W; SOT-323_SC-70; Mouser-Nr. 637-BAT54W
D101: ES2G; D_SMB_Handsoldering; Mouser Nr. 603-ES2G
D102, D103: LED_G; LED_0805_2012Metric
J100: HT_en; PinHeader_1x02_P2.54mm_Vertical
L100: 33u, 4.2A; L_12x12mm_H8mm; Mouser Nr. 7447709330
Q100: MMBTA42; SOT-23
Q101: IRF7820; SO-8_3.9x4.9mm_P1.27mm
R100, R107, R113: 1k; R_0805_2012Metric_Pad1.20x1.40mm_HandSolder
R101, R102: 100k; R_0805_2012Metric_Pad1.20x1.40mm_HandSolder
R103: 2k; R_0805_2012Metric_Pad1.20x1.40mm_HandSolder; Mouser Nr. 603-RC0805FR-132KL
R104: 4k12; R_0805_2012Metric_Pad1.20x1.40mm_HandSolder; Mouser Nr. 603-RC0805FR-074K12L
R105: 60k4; R_0805_2012Metric_Pad1.20x1.40mm_HandSolder; Mouser Nr. 603-RE0805FRE0747KL
R106: 0R; R_0805_2012Metric_Pad1.20x1.40mm_HandSolder
R108: 0R1; R_1206_3216Metric_Pad1.30x1.75mm_HandSolder; Mouser Nr. 660-UR73VH2BTTDR100F
R109: 634k; R_1206_3216Metric_Pad1.30x1.75mm_HandSolder; Mouser Nr. 71-CRCW0805634KFKEA
R110: 7k68; R_1206_3216Metric_Pad1.30x1.75mm_HandSolder; Mouser Nr. 603-RC0805FR-077K68L
R111, R112: 330k; R_0805_2012Metric_Pad1.20x1.40mm_HandSolder; Mouser Nr. 603-AC0805FR-07330KL
TP20, TP24: TestPoint_Small; TestPoint_Pad_D1.5mm
U100: UCC3803; SOIC-8_3.9x4.9mm_P1.27mm; Mouser Nr. 595-UCC3803DTR

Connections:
/HV Power Supply/COMP: C103.2, D100.1 (A), U100.1 (COMP)
/HV Power Supply/CS: C107.1, R104.1, R107.1, U100.3 (CS)
/HV Power Supply/FB: C103.1, C109.2, R109.2, R110.1, U100.2 (FB)
/HV Power Supply/FET_Drain: C108.1, D101.2 (A), L100.2, Q101.5 (D), Q101.6 (D), Q101.7 (D), Q101.8 (D)
/HV Power Supply/FET_Source: Q101.1 (S), Q101.2 (S), Q101.3 (S), R107.2, R108.2
/HV Power Supply/LED_ht: C114.1, D102.2 (A), R111.2, R112.2
/HV Power Supply/OUT: R106.1, U100.6 (OUT)
/HV Power Supply/RC: C102.1, R105.1, U100.4 (RC)
/HV Power Supply/REF: C104.1, R104.2, R105.2, U100.8 (REF)
/~EN: D103.2 (A), J100.2; also elsewhere on the board
GND: C100.2, C101.2, C102.2, C104.2, C105.2, C106.2, C107.2, C108.2, C110.2, C111.2, C112.2, C114.2, D102.1 (K), Q100.2 (E), R102.2, R108.1, R110.2, R113.1, U100.5 (GND); also elsewhere on the board
HT: C109.1, C110.1, C111.1, C112.1, D101.1 (K), R109.1, R111.1, R112.1, TP20.1; also elsewhere on the board
unnamed: C101.1, D100.3 (K), Q100.3 (C), R102.1, R103.2
unnamed: D103.1 (K), R113.2
unnamed: J100.1, R100.1
unnamed: Q100.1 (B), R100.2, R101.2
unnamed: Q101.4 (G), R106.2
VDD: C100.1, C105.1, C106.1, L100.1, R101.1, R103.1, TP24.1, U100.7 (VCC); also elsewhere on the board

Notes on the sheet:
FIXED: New inductor, new output cap and diffrent frequency resistorn New MosFET (IRF7820 from fds2734)
fsw = 50kHz
1/2W!

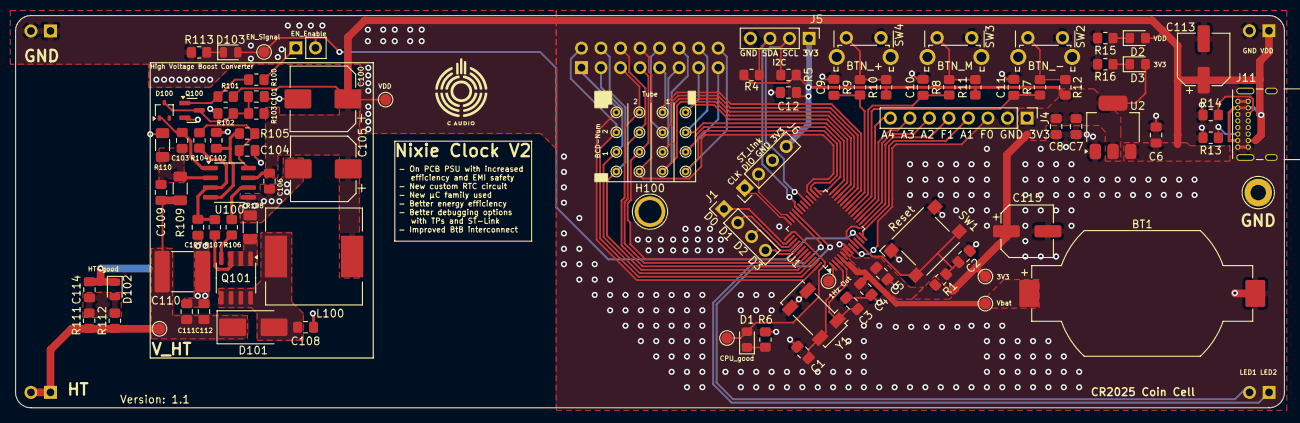
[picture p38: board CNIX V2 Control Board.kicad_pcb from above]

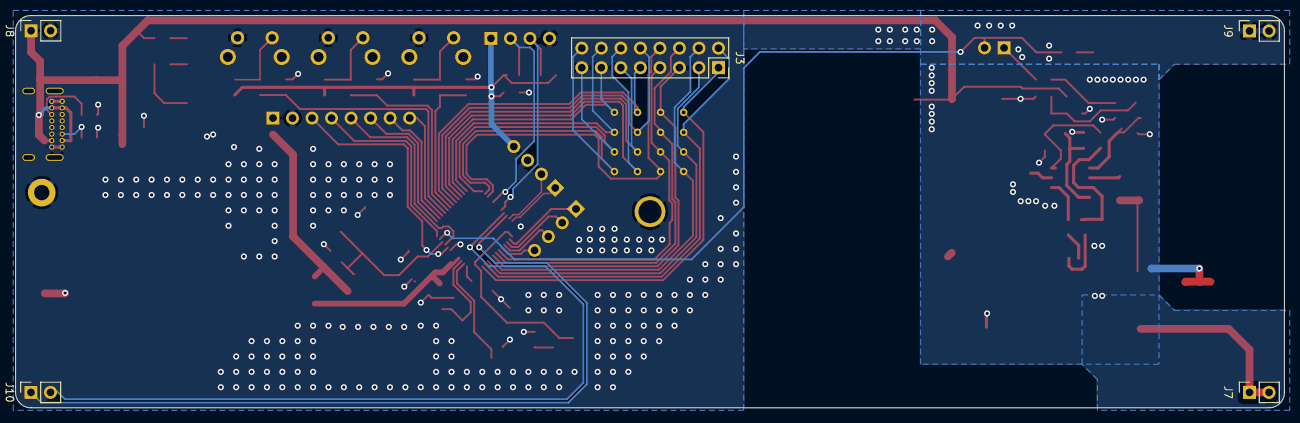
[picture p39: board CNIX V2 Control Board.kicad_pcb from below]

Board: 2 copper layers, 165.0 x 51.0 mm, 111 parts (5 on the bottom side), 68 nets.

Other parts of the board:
R6: 4k7; R_0805_2012Metric_Pad1.20x1.40mm_HandSolder

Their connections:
GND: R6.2; also elsewhere on the board
unnamed 52: R6.1; also elsewhere on the board

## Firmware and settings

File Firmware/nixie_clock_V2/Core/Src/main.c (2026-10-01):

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
/* Includes ------------------------------------------------------------------*/
#include "main.h"

/* USER CODE BEGIN Includes */
#include "cmsis_gcc.h"
#include "stm32g051xx.h"
#include "stm32g0xx.h"
#include "stm32g0xx_hal.h"
#include "stm32g0xx_hal_def.h"
#include "stm32g0xx_hal_gpio.h"
#include "stm32g0xx_hal_rtc.h"
#include "stm32g0xx_hal_rtc_ex.h"
#include "stm32g0xx_hal_tim.h"
#include <stdint.h>

#include "stdio.h"
#include "output_tube.h"
#include "menu.h"
#include "display.h"
#include "timeStuff.h"
#include "dcf77.h"
/* USER CODE END Includes */

I2C_HandleTypeDef hi2c1;

RTC_HandleTypeDef hrtc;

TIM_HandleTypeDef htim1;
TIM_HandleTypeDef htim2;

/* USER CODE BEGIN PV */

time_date_DataDigital TD_data = {0};
time_date_DataDigital TD_data_TEST = {0};

menu menu_position = menuTIME;
menu menu_position_old = menuTIME;

uint8_t submenu_pos = 0;

tubeDisplay nixieDisplay = {0};

DCF77_TimeTypeDef dcf_time;

volatile uint8_t tick_flag = isNotSet;
volatile uint8_t counter_seconds = 0;
volatile uint16_t tick_count = 0;

uint8_t recal_failed_cnt = 0;

/**
 * Value of the button being pressed.
 * 1: MINUS
 * 2: MENU
 * 3: PLUS
 */
volatile int8_t btn_flag_menu  = 0;
volatile int8_t btn_flag_plus  = 0;
volatile int8_t btn_flag_minus = 0;

uint8_t time_update_flag = 0;
volatile uint8_t timeDate_recal_flag = 0;
uint8_t out_of_calibration_flag = 0;

/**
 * @brief Flag to signal a change in the system via I/O or Timeout
 *  gets set whenever a button is pressed and should be reset when it is used inside a function, not everytime the loop repeats
 */
volatile uint8_t sys_update_flag = 0;

uint8_t btn_pressed_flag = isNotPressed;

//for when the sensor is being used
volatile uint8_t sensor_flag = 0;

uint8_t id_read = 0b0011;
//IDs for all available driver boards
uint8_t addon_dcf77 = 0;

/* USER CODE END PV */

void SystemClock_Config(void);
static void MX_GPIO_Init(void);
static void MX_I2C1_Init(void);
static void MX_RTC_Init(void);
static void MX_TIM1_Init(void);
static void MX_TIM2_Init(void);
/* USER CODE BEGIN PFP */

/**
 * @brief Callback for when the dcf77 driver completes a valid minute readout
 * @param time -> the time struct from dcf77 driver which contains the current time.
 */
void DCF77_MinuteCallback(DCF77_TimeTypeDef* time);

/**
 * @brief: Check for installed addons via ID pins D2 and D3 and sets corresponding flag
 * Addons:
 * 0 -> DCF77
 */
void check_for_addons(void);

/**
 * @brief Uses the time data from main time and date structure to give a 16 bit representation of the current time
 * @param: _time_date_data -> pointer to main time and date containing struct.
 * @retval Return 16 bit time data fit for direct outputting onto PORTB of the micro
 */
uint16_t set_tube_numbers_time(time_date_DataDigital* _time_date_data);

/**
 * @brief Uses the time data from main time and date structure to give a 16 bit representation of the current date
 * @param: _time_date_data -> pointer to main time and date containing struct.
 * @retval Return 16 bit date data fit for direct outputting onto PORTB of the micro
 */
uint16_t set_tube_numbers_date(time_date_DataDigital* _time_date_data);

//-----------------------------------------------------------Menu Stuff

/**
 * @brief: Dispalys the current time on the nixies. Nixie illumination is based upon start and stop times. 
 */
void menu_mainTime();

/**
 * @brief: Dispalys the current date on the nixies. Nixie illumination is based upon start and stop times.
 */
void menu_mainDate();

/**
 * @brief: TODO: Dispalys the current temperaturee (left) and humidity (right) on the nixies. Nixie illumination is based upon start and stop times.
 */
void menu_Sensor();

/**
 * @brief: When out of timeframe for on times, display current time. Should have a timeout of 10s
 */
void menu_peekTime();

/**
 * @brief: Lets one manually set start and stop times. There are 2 sets of Start/Stop times, one for the morning, one for the evening.
 * @param: _submenu_pos -> pointer to the global variable submenu_pos to cicle through the numbers.
 * @param: _Tdata_startStop -> pointer to main time containing struct.
 */
void menu_startStop(uint8_t* _submenu_pos, time_date_DataDigital* _Tdata_startStop);

/**
 * @brief: Lets one manually set the time. TODO: Gets disabled when DCF77 module is used.
 * @param: _submenu_pos -> pointer to the global variable submenu_pos to cicle through the numbers.
 * @param: _Tdata -> pointer to main time containing struct.
 */
void menu_timeSet(uint8_t* _submenu_pos, time_date_DataDigital* _Tdata);

/**
 * @brief: Timeout function to return to menuTIME after a set amount of seconds. Depends on the tick_count global variable (increased by RTC 1Hz out, reset every time a button is pressed via IRQ)
 * @param: _timeoutValue -> timeout value in seconds
 */
void menu_timeout(uint8_t _timeoutValue);

/**
 * @brief: Handles blinking of display elements
 * @retval: 1 or 0, alternating every BLINK_TIME
 */
uint8_t blinkState(void);

/**
 * @brief: Handles blinking of display elements
 * @retval: 1 or 0, alternating every _blink_time
 */
uint8_t blinkState_custom(uint16_t _blink_time);

/**
 * @brief Checks if current time is in the range of on hours. If no, turn display off. Has to be called after restoring backed up start stop data
 * @param _TD_data -> Main struct for time data to check for start and stop hours
 * @param _nixieDisplay -> Main struct for display data to change status state. 
 * @retval 0 if current state should be off, 1 if current state should be on.
 */
uint8_t startStop_check(time_date_DataDigital* _TD_data, tubeDisplay* _nixieDisplay);


//-----------------------------------------------------------Time Stuff

/**
 * @brief Checks for triggers of daylight saving time (last sunday in march or october ect.) and sets the RTC flags correspondingly
 * @param _DST      -> value from check_for_DST or 0 for summertime and 1 for wintertime. 2 for Error (does nothing)
 * @param hrtc      -> RTC Struct from HAL
 */
void set_for_DST(RTC_HandleTypeDef* hrtc, uint8_t _DST);

/**
 * @brief Checks for triggers of daylight saving time (last sunday in march or october ect.)
 * @param _TD_data  -> Main struct for time data
 * @param hrtc      -> RTC Struct from HAL
 * @retval 0 if sumemrtime trigger, 1 if wintertime trigger
 */
uint8_t check_for_DST(RTC_HandleTypeDef* hrtc, time_date_DataDigital* _TD_data);

//RTC related functions
/**
 * @brief reads the BKP Register DR2, which contains a 32bit combination of all start and stop times.
 * Puts them into TD_data main data structure in order
 * @param _TD_data main time structure containing all start and stop times
 */
void time_read_startStop_bkp  (time_date_DataDigital* _TD_data);

/**
 * @brief writes to the BKP Register DR2 from main time structure, which contains a 32bit combination of all start and stop times.
 * @param _TD_data main time structure containing all start and stop times
 */
void time_write_startStop_bkp (time_date_DataDigital* _TD_data);

//-----------------------------------------------------------DCF77 time calibration stuff

/**
 * @brief Check for the number of failed recalibration attempts in the RTC_BKUP_REG DR0 
 * @param _hrtc -> RTC handle
 * @retval Number of previous recalibration attempts (if 0, then rtc battery is dead)
 */
uint16_t check_for_reCalAttempts(RTC_HandleTypeDef* _hrtc);

/**
 * @brief ncrements the number of recalibration attempts by one in the bkp register DR0
 * @param _hrtc -> RTC handle
 * @retval Error status (0 = OK, 1 = ERROR)
 */
HAL_StatusTypeDef increment_reCalAttempts(RTC_HandleTypeDef* _hrtc);

/**
 * @brief sets the bkp register DR0 to 1. If it is 0 -> RTC battery is dead
 * @param _hrtc -> RTC handle
 * @retval Error status (0 = OK, 1 = ERROR)
 */
HAL_StatusTypeDef clear_reCalAttempts(RTC_HandleTypeDef* _hrtc);

/**
 * @brief Recalibrates the time and date from DCF77 module
 * @param _TD_data main time and date struct 
 * @param _timeout_ms timeout value in seconds after which an error is returned
 * @retval HAL_StatusTypeDef 0 = HAL_OK, 1 = HAL_ERROR
 */
HAL_StatusTypeDef time_recalibration(time_date_DataDigital* _TD_data, const uint16_t _timeout_s);

/**
 * @brief checks if recal attempt value is in acceptable borders
 * @param _hrtc -> RTC handle
 * @retval 0 -> in calibration, 1 -> out of calibration
 */
uint8_t check_for_calibration(RTC_HandleTypeDef* _hrtc);

/**
 * @brief: combines multiple dcf77 reclatibration functions in one. Recalibrates time and sets the bkp register dr0 correspondingly
 * @param: _TD_data main time and date struct 
 * @param: _timeout_ms timeout value in seconds after which an error is returned
 * @param: _hrtc -> RTC handle
 */
HAL_StatusTypeDef DCF77_TimeRecalibration(time_date_DataDigital* _TD_data, const uint16_t _timeout_s, RTC_HandleTypeDef* _hrtc);

//-----------------------------------------------------------Button Stuff

/**
 * @brief Resets all button flags at once
 */
void resetBtnFlags();

void handle_btn (menu* _pos);
void handle_btnPlus (menu* _pos);
void handle_btnMinus (menu* _pos);
void handle_btnMenu (menu* _pos);

/* USER CODE END PFP */

/**
  * @brief  The application entry point.
  * @retval int
  */
int main(void)
{

  /* MCU Configuration--------------------------------------------------------*/

  /* Reset of all peripherals, Initializes the Flash interface and the Systick. */
  HAL_Init();

  /* Configure the system clock */
  SystemClock_Config();

  /* Initialize all configured peripherals */
  MX_GPIO_Init();
  MX_I2C1_Init();
  MX_RTC_Init();
  MX_TIM1_Init();
  MX_TIM2_Init();
  /* USER CODE BEGIN 2 */

  HAL_TIM_Base_Start_IT(&htim1);

  //Initialize the RTC
  HAL_RTC_Init(&hrtc);

  /**
   * If the random number stored in the backup register is diffrent from the current value, its not updating the Time and Date. 
   * Seed, Time and Date are stored in makros 
   */
   if(HAL_RTCEx_BKUPRead(&hrtc, RTC_SEED_BKP_REGISTER) != RANDOM_SEED_UPDATE) {
    setTime(CURRENT_TIME_HOURS, CURRENT_TIME_MINUTES, CURRENT_TIME_SECONDS);
    setDate(CURRENT_DATE_YEAR, CURRENT_DATE_MONTH, CURRENT_DATE_WEEKDAY, CURRENT_DATE_DAY);
  }

  //If cal wasn't successful for 3 days or rtc battery is dead -> out of calibration
  if(check_for_calibration(&hrtc)) out_of_calibration_flag = 1;
  
  //Check the D2 and D3 bits for addon boards. No board -> 0b11
  check_for_addons();

  //If module is found -> initiate it. When out of calibration -> calibrate it
  if(addon_dcf77) {
    DCF77_Init(&htim2);
    DCF77_RegisterCallback(DCF77_MinuteCallback);

    if(out_of_calibration_flag) DCF77_TimeRecalibration(&TD_data, 5*60, &hrtc);
  }

  /**
   * Retrieve time and date data from the running RTC
   * Try 10 times or till a HAL_OK is retrieved
   * Disable IRQ while doing this to prevent faulty time data
   */
  __disable_irq();
  
  if(getTimeDate(&TD_data) != HAL_OK) {
    HAL_StatusTypeDef _Status = HAL_ERROR;

    for(uint8_t tries = 0; tries < 10; tries++) {
      _Status = getTimeDate(&TD_data);
      if(_Status == HAL_OK) break;
    }
  }
  __enable_irq();

  //Set the Front LEDs On
  output_front_led(1, 1);

  //Check for daylight saving time
  set_for_DST(&hrtc, check_for_DST(&hrtc, &TD_data));

  //Retrieve start and stop time from RTC backup register and push them to the main time struct
  time_read_startStop_bkp(&TD_data);

  //Check if start stop times are reached and change the corresponding bit in the nixieDisplay struct
  startStop_check(&TD_data, &nixieDisplay);

  //Output current time to main time struct
  nixieDisplay.displayDigitOutput = set_tube_numbers_time(&TD_data);

  //output time data to the display struct
  output_to_tubesNEW(&nixieDisplay);

  //Set the HT supply state to the corresponding state in display struct
  ht_supply_state(&nixieDisplay);

  /* USER CODE END 2 */

  /* Infinite loop */
  /* USER CODE BEGIN WHILE */

  while (1)
  {

    if(addon_dcf77) {
      //does something once a day at 2 (set by Alarm A interrupt handler)
      if(timeDate_recal_flag) {
        DCF77_TimeRecalibration(&TD_data, 20*60, &hrtc);
        timeDate_recal_flag = 0;
      }
    }

    switch(menu_position) {
      case menuTIME:
        menu_mainTime();
        break; 
      case menuDATE:
        menu_mainDate();
        menu_timeout(DISPLAY_MENU_TimeDateSensor_TIMEOUT);
        break;
      case menuSENSOR:
        menu_Sensor();
        menu_timeout(DISPLAY_MENU_TimeDateSensor_TIMEOUT);
        break;
      case menuPEEKTIME:
        menu_peekTime();
        menu_timeout(10);
        break;
      case menuStartStop:
        menu_startStop(&submenu_pos, &TD_data);
        menu_timeout(DISPLAY_MENU_X_TIMEOUT);
        break;
      case menuTimeEdit:
        if(out_of_calibration_flag || !addon_dcf77) {     //If clock is out of calibration OR dcf77 addon is not pluged in -> enable timeSet menu
          menu_timeSet(&submenu_pos, &TD_data);
          menu_timeout(DISPLAY_MENU_X_TIMEOUT);
          break;
        }
        menu_position++;
        break;
      case menuOVERFLOW:
        menu_position = menuTIME;
        break;
      default: 
        menu_position = menuTIME;
        break;
    }

    if((nixieDisplay.displayStatus != nixieDisplay.displayStatus_old) || (menu_position != menuTIME)) {
      if(menu_position != menuTIME) {
        nixieDisplay.displayStatus = 1;
        ht_supply_state(&nixieDisplay);
      } else {
        ht_supply_state(&nixieDisplay);
      }
      nixieDisplay.displayStatus_old = nixieDisplay.displayStatus;
    }

    if(menu_position != menuStartStop && menu_position != menuTimeEdit) {
      output_to_tubesNEW(&nixieDisplay);  //Updates the tube display only when it should be automatically updated
    }

    /* USER CODE END WHILE */

    /* USER CODE BEGIN 3 */
  }
  /* USER CODE END 3 */
}

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
/* USER CODE BEGIN 4 */

HAL_StatusTypeDef setTime(uint8_t hour, uint8_t minute, uint8_t second) {
  RTC_TimeTypeDef sTime = {0};
  sTime.Hours = hour;
  sTime.Minutes = minute;
  sTime.Seconds = second;
  sTime.SubSeconds = 0x0;

  if (HAL_RTC_SetTime(&hrtc, &sTime, RTC_FORMAT_BIN) != HAL_OK)
  {
    return HAL_ERROR;
  }
  //HAL_RTC_DST_Sub1Hour(&hrtc);  // TODO Daylight Saving Time,check for last sunday of march and last sunday in october to set opr unset DST. 
  return HAL_OK;
}

HAL_StatusTypeDef setDate(uint8_t year, uint8_t month, uint8_t weekday, uint8_t date) { //weekday->Monday = 1, date->which day in month (0-31) 
  RTC_DateTypeDef sDate = {0};
  sDate.WeekDay = weekday;
  sDate.Month = month;
  sDate.Date = date;
  sDate.Year = year;

  if (HAL_RTC_SetDate(&hrtc, &sDate, RTC_FORMAT_BIN) != HAL_OK)
  {
    return HAL_ERROR;
  }

  HAL_RTCEx_BKUPWrite(&hrtc, RTC_BKP_DR1, RANDOM_SEED_UPDATE);
  
  return HAL_OK;
}

HAL_StatusTypeDef getTimeDate(time_date_DataDigital* dTimeDate) {
  RTC_DateTypeDef gDate;
  RTC_TimeTypeDef gTime;
  uint8_t _error_count = 0;

  //Get current time
  if(HAL_RTC_GetTime(&hrtc, &gTime, RTC_FORMAT_BIN) != HAL_OK) _error_count++;

  //Get current date
  if(HAL_RTC_GetDate(&hrtc, &gDate, RTC_FORMAT_BIN) != HAL_OK) _error_count++;

  dTimeDate->hours = gTime.Hours;
  dTimeDate->minutes = gTime.Minutes;
  dTimeDate->seconds = gTime.Seconds;

  dTimeDate->day = gDate.Date;
  dTimeDate->weekday = gDate.WeekDay;
  dTimeDate->month = gDate.Month;
  dTimeDate->year = gDate.Year;

  if(_error_count != 0) return HAL_ERROR;
  return HAL_OK;
}

uint16_t set_tube_numbers_time(time_date_DataDigital* _time_date_data) {

  //Start by extracting the single numbers out of the time struct to fuse them to a 16-Bit number later

  //Hours
  //calculate the tens
  uint8_t hours_tens = _time_date_data->hours / 10;
  //calculate the ones
  uint8_t hours_ones = _time_date_data->hours % 10;

  //Minutes
  //calculate the tens
  uint8_t minutes_tens = _time_date_data->minutes / 10;
  //calculate the ones
  uint8_t minutes_ones = _time_date_data->minutes % 10;

  return(combine_4bit_numbers(hours_tens, hours_ones, minutes_tens, minutes_ones));
}

uint16_t set_tube_numbers_date(time_date_DataDigital* _time_date_data) {

  //Start by extracting the single numbers out of the time struct to fuse them to a 16-Bit number later

  //Hours
  //calculate the tens
  uint8_t month_tens = _time_date_data->month / 10;
  //calculate the ones
  uint8_t month_ones = _time_date_data->month % 10;

  //Minutes
  //calculate the tens
  uint8_t day_tens = _time_date_data->day / 10;
  //calculate the ones
  uint8_t day_ones = _time_date_data->day % 10;

  /*Works miracilously perfectly :) but useless unless the PCB changes to accomondate for the correct pin order
  uint16_t _timeData_port = (hours_tens << 12) | (hours_ones << 8) | 
                            (minutes_tens << 4) | minutes_ones;
  */

  return(combine_4bit_numbers(day_tens, day_ones, month_tens, month_ones));
}

void menu_mainTime() {
  output_blink_front_leds(solid);

  if(sys_update_flag) {
    getTimeDate(&TD_data);
    nixieDisplay.displayDigitOutput = set_tube_numbers_time(&TD_data);

    startStop_check(&TD_data, &nixieDisplay);

    set_for_DST(&hrtc, check_for_DST(&hrtc, &TD_data));

    sys_update_flag = 0;
  }

  if(tick_flag == isSet) { //flag set by interrupt by RTC on 1Hz

    getTimeDate(&TD_data);      //Get time from RTC registers

    //Update display data, nixies dont have seconds!
    if(TD_data.seconds == 0) {
      nixieDisplay.displayDigitOutput = set_tube_numbers_time(&TD_data);
      set_for_DST(&hrtc, check_for_DST(&hrtc, &TD_data));
    }

    startStop_check(&TD_data, &nixieDisplay);

    tick_flag = reset; //reset update flag
  }

  handle_btn(&menu_position);
}

void menu_mainDate() {
  output_blink_front_leds(solidBot);

  if(sys_update_flag) {
    getTimeDate(&TD_data);
    nixieDisplay.displayDigitOutput = set_tube_numbers_date(&TD_data);

    sys_update_flag = 0;
  }

  if(tick_flag == isSet) {
    
    getTimeDate(&TD_data);

    nixieDisplay.displayDigitOutput = set_tube_numbers_date(&TD_data);

    tick_flag = reset;
  }

  handle_btn(&menu_position);
}

void menu_Sensor() {
  output_blink_front_leds(blinkBoth);

  if(sys_update_flag) {
    nixieDisplay.displayDigitOutput = combine_4bit_numbers(9, BLANK, 9, BLANK); //PLACEHOLDER

    nixieDisplay.displayStatus = 1;

    if(nixieDisplay.displayStatus != nixieDisplay.displayStatus_old) {
      ht_supply_state(&nixieDisplay);
      nixieDisplay.displayStatus_old = nixieDisplay.displayStatus;
    }

    sys_update_flag = 0;
  }

  if(tick_flag == isSet) {

    tick_flag = reset;
  }

  handle_btn(&menu_position);
}

void menu_startStop(uint8_t* _submenu_pos, time_date_DataDigital* _Tdata_startStop) {

  output_blink_front_leds(blinkTop);

  static uint8_t temp_time;

  //if somethings need to happen only once getting into this menu
  if(menu_position_old != menu_position) {
    *_submenu_pos = 0;
    temp_time = _Tdata_startStop->startHour1;
    menu_position_old = menu_position;
  }

  //handle_btn(&menu_position);

  if(btn_flag_plus) {
    temp_time = (temp_time + 1) % 24;
    btn_flag_plus = 0;
  }

  if(btn_flag_minus) {
    temp_time = (temp_time + 23) % 24;
    btn_flag_minus = 0;
  }

  if(btn_flag_menu) {
    switch(*_submenu_pos) {
      case 0:
        _Tdata_startStop->startHour1 = temp_time;
        temp_time = _Tdata_startStop->stopHour1;
        (*_submenu_pos)++;
        break;
      case 1:
        _Tdata_startStop->stopHour1 = temp_time;
        temp_time = _Tdata_startStop->startHour2;
        (*_submenu_pos)++;
        break;
      case 2:
        _Tdata_startStop->startHour2 = temp_time;
        temp_time = _Tdata_startStop->stopHour2;
        (*_submenu_pos)++;
        break;
      case 3:
        _Tdata_startStop->stopHour2 = temp_time;
        *_submenu_pos = 0;
        time_write_startStop_bkp(_Tdata_startStop);
        menu_position++;
        break;
    }
    btn_flag_menu = 0;
  }

  output_to_tubes(combine_4bit_numbers((temp_time/10), (temp_time%10), 0, 0));
}
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

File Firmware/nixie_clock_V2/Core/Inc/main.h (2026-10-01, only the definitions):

#define RTC_SEED_BKP_REGISTER RTC_BKP_DR1
#define RTC_START_STOP_BKP_REGISTER RTC_BKP_DR2
#define RTC_RECAL_BKP_REGISTER RTC_BKP_DR0
#define RANDOM_SEED_UPDATE 0x2341
#define CURRENT_TIME_HOURS   9
#define CURRENT_TIME_MINUTES  42
#define CURRENT_TIME_SECONDS  0
#define CURRENT_DATE_YEAR    26
#define CURRENT_DATE_MONTH   9
#define CURRENT_DATE_DAY     19
#define CURRENT_DATE_WEEKDAY  6
#define DISPLAY_MENU_RESET_TIME 750
#define TICK_INTERVAL 500
#define TIMEOUT_DCF77 (20 * 60)
#define DISPLAY_MENU_TimeDateSensor_TIMEOUT 10
#define DISPLAY_MENU_X_TIMEOUT 30
#define set 1
#define true 1
#define isSet 1
#define isPressed 1
#define reset 0
#define false 0
#define isNotSet 0
#define isNotPressed 0
#define BLANK 0b1010  //Out of bounds for the CD4028 chip, to display a blank
#define ht_EN_Pin GPIO_PIN_0
#define ht_EN_GPIO_Port GPIOA
#define addon_en_Pin GPIO_PIN_1
#define addon_en_GPIO_Port GPIOA
#define btn_minus_Pin GPIO_PIN_5
#define btn_minus_GPIO_Port GPIOA
#define btn_minus_EXTI_IRQn EXTI4_15_IRQn
#define btn_menu_Pin GPIO_PIN_6
#define btn_menu_GPIO_Port GPIOA
#define btn_menu_EXTI_IRQn EXTI4_15_IRQn
#define btn_plus_Pin GPIO_PIN_7
#define btn_plus_GPIO_Port GPIOA
#define btn_plus_EXTI_IRQn EXTI4_15_IRQn
#define co1_3_Pin GPIO_PIN_0
#define co1_3_GPIO_Port GPIOB
#define co1_2_Pin GPIO_PIN_1
#define co1_2_GPIO_Port GPIOB
#define co1_1_Pin GPIO_PIN_2
#define co1_1_GPIO_Port GPIOB
#define co1_0_Pin GPIO_PIN_10
#define co1_0_GPIO_Port GPIOB
#define co0_3_Pin GPIO_PIN_11
#define co0_3_GPIO_Port GPIOB
#define co0_2_Pin GPIO_PIN_12
#define co0_2_GPIO_Port GPIOB
#define co0_1_Pin GPIO_PIN_13
#define co0_1_GPIO_Port GPIOB
#define co0_0_Pin GPIO_PIN_14
#define co0_0_GPIO_Port GPIOB
#define co2_0_Pin GPIO_PIN_15
#define co2_0_GPIO_Port GPIOB
#define led_sig_bot_Pin GPIO_PIN_11
#define led_sig_bot_GPIO_Port GPIOA
#define led_sig_top_Pin GPIO_PIN_12
#define led_sig_top_GPIO_Port GPIOA
#define pwr_led_Pin GPIO_PIN_15
#define pwr_led_GPIO_Port GPIOA
#define id_bit0_Pin GPIO_PIN_2
#define id_bit0_GPIO_Port GPIOD
#define id_bit1_Pin GPIO_PIN_3
#define id_bit1_GPIO_Port GPIOD
#define co2_1_Pin GPIO_PIN_3
#define co2_1_GPIO_Port GPIOB
#define co2_2_Pin GPIO_PIN_4
#define co2_2_GPIO_Port GPIOB
#define co2_3_Pin GPIO_PIN_5
#define co2_3_GPIO_Port GPIOB
#define co3_0_Pin GPIO_PIN_6
#define co3_0_GPIO_Port GPIOB
#define co3_1_Pin GPIO_PIN_7
#define co3_1_GPIO_Port GPIOB
#define co3_2_Pin GPIO_PIN_8
#define co3_2_GPIO_Port GPIOB
#define co3_3_Pin GPIO_PIN_9
#define co3_3_GPIO_Port GPIOB

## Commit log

2025-03-11 first commit, added boards
    [CNIX V2 Control Board-B_Cu.gbr, CNIX V2 Control Board-B_Mask.gbr, CNIX V2 Control Board-B_Paste.gbr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]
2025-04-03 added bom and populated board
    [CNIX V2 Control Board.kicad_pcb]
2025-12-16 fixed stuff
    [CNIX V2 Tube Board.kicad_pcb]
2025-12-17 added bit masks for each tube
2025-12-17 added tube bit output
2025-12-17 fully added tube bit changing and display debug check
2025-12-17 fixed schematic
    [CNIX V2 Control Board.kicad_pcb, psu.kicad_sch]
2025-12-17 fixed output caps and routung on pcb. Version Bump to 1.1
    [CNIX V2 Control Board.kicad_pcb]
2025-12-17 found a bug, that the tubes are wired abckwards, needs to be fixed via new board
    [CNIX V2 Tube Board.kicad_pcb]
2025-12-17 added warning for tube fail
    https://www.mouser.de/ProductDetail/TDK/C5750X7T2E225K250KA?qs=vG%252BtRDh6KwCR7tEmlFz%2FKw%3D%3D
    exit
    quit
    [CNIX V2 Control Board.kicad_pcb, CNIX V2 Tube Board.kicad_pcb, CNIX V2 Tube Board.kicad_sch]
2026-09-19 Added simple debug features
    [CNIX V2 Control Board.kicad_pcb, CNIX V2 Control Board.kicad_sch, CNIX V2 Tube Board.kicad_pcb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]
2026-09-24 redid the entire menu structure with new file structure
    [CNIX V2 Control Board.kicad_sch]
2026-09-24 found bug with menu_position
    [main.c]
2026-09-28 Changed handling of buttons to flag based pointer system
2026-09-30 redid timer config and edited dcf driver
2026-10-01 finished dcf driver usage and logic
2026-10-01 cleanup of project data and files
    [CNIX V2 Control Board.kicad_pcb, CNIX V2 Control Board.kicad_sch, CNIX V2 Tube Board.kicad_pcb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]
2026-10-01 reinitiated directories to apply gitignore
    [CNIX V2 Control Board-B_Cu.gbr, CNIX V2 Control Board-B_Mask.gbr, CNIX V2 Control Board-B_Paste.gbr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]
2026-10-01 Edited README and added new pictures
    [CNIX V2 Control Board.step, CNIX V2 Tube Board.step, Case.FCStd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]
2026-10-01 added redme paragraph about the control board
2026-10-01 Update README with BOM optimization details
    Added BOM optimization to reduce the number of unique parts.

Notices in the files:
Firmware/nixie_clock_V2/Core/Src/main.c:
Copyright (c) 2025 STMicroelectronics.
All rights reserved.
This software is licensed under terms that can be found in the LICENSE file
